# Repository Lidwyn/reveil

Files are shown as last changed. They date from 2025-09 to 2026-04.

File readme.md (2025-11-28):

# Alarm Clock Project

A fully custom-built **embedded alarm clock** designed from scratch, featuring a hardware-level implementation using an **ATmega328P**, **7-segment displays**, a **real-time clock (RTC)** module, and a modular audio system with microSD song storage.
This project integrates **embedded firmware**, **electronics design**, **PCB layout**, **CAD**, and **technical documentation**.

> This project is **still in progress**, every features or documents mentionned here might **not be complete or avaible yet**.

## Features
+ **Times display**
+ **Next alarm** on secondary display
+ Up to **15 one time (unique) and 15 weekly (non unique) independent alarms**
+ **Night Mode** - complete display blackout
+ **RTC-based accurate timekeeping** (with battery backup)

## Tech Stack & Tools

### Firmware
+ **Atmega328P** (bare-metal Arduino-style development)
+ **Arduino language** via **PlatformIO**
+ Interrupt-drivern logic
+ Low-power modes

### Elecrtonics & PCB
+ **Kicad** for schematic capture and PCB layout
+ Multi-voltage power stage (5V and 3.3V)

### Mechanical Design
+ **CATIA** for enclosure & mechanical parts

### Documentation
+ **LaTeX** for the user and technical manuals

## Project Architure
```
/Prog/          -> PlatformIO project for MCU firmware
/Schematic/     -> KiCad schematics & PCB files
/cad/           -> CATIA models for enclosure
/Latex/         -> Latex (and pdf) manual
```

## How It Works
1. The **ATmega328P** handles alarm logic, display control, and power management.
2. A **DS3231 RTC** maintains accurate time with battery backup. Through **I2C bus**.
3. On the same chips as the DS3231, we have an **AT24C32 EEPROM** that store the multiples alarms, the volume, and the brightness setup. Also with battery backup and through the same **I2C bus**.
4. Two four **7-segment display** and **9 leds**, driven by two **MAX7219** are in charge of the display. Through **SPI bus**.
5. A **DFPlayer** handle the audio, stored on a **microSD card**, with an integrated amplifier and an external speaker. Through a **Serial Port bus**.
5. 6 buttons for setup.

Find more information about the GUI on the manual:
- [Manuel fr](Latex/Manuel.pdf)

## Learning Objectives & Personal Development
This project in an opportunity to build **foundational embedded-systems skills** from scratch, inculding:
+ **Embedded C++ developpement** on microcontrollers
+ Designing and debugging **digital and mixed-signal electronics**
+ Understanting **RTCs**, **SD interfaces**, **multiplexing**, and **interrupt-driven systems**
+ **PCB worklow** from schematic to layout to fabrication
+ **Mechanical design** for electronics
+ Writing **clear and precise technical documentation** in **LaTeX**

## What I'm Most Proud Of
+ Implementing **deep sleep and interrupt-driven wake-up**, dramatically
reducing power consumption
+ Designing a **clean dual-voltage system** that support both 5V and 3.3V as the ATmega328P consumme less current at 3.3V further improving power consumption
+ Using **logical Mosfet** to cut unactive chips such as the audio chips, reducing noise to zero and reducing consumption
+ **Creating the entire device end-to-end** : firmware, electonics, PCB, mechanical parts, and documentation
+ Gaining practical **embedded engineering experience** from low to no prior knowledge

## How to Build / Run
### Hardware
1. Burn bootloader on the ATmega328P
2. Flash your microSD on FAT32
3. Insert microSD with you preferred alarm audio file with this typo `0001WhateverName.mp3`

### Firmware
1. Install **PlatformIO** (VS Codium extension)
2. Plug the alarm clock
3. Plug your computer into the USB C to seral adapter of the card
4. Adjust `upload_port = COM15` to your specific usb port in `/Prog/platformio.ini`
5. Upload firmware with `pio run --target upload`

## Status
This project is **still in development** :
+ Firmware : **working**, new features should be added and bugs fixed
+ PCB : **schematic is done**, PCB layout is not
+ Mechanical part : not started
+ Documenation : just the base of the french user manual version

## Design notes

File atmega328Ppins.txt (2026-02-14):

            +----_----+
  RESET   1 |PC6   PC5| 28 SCL
   RX->   2 |PD0   PC4| 27 SDA
   TX->   3 |PD1   PC3| 26 DS3231 CLK
Bouton<   4 |PD2   PC2| 25 
BoutonS   5 |PD3   PC1| 24 
BoutonA   6 |PD4   PC0| 23
    VCC   7 |         | 22 GND
    GND   8 |         | 21 AREF
DFP power 9 |PB6      | 20 AVCC
         10 |PB7   PB5| 19 MOSI
Bouton+  11 |PD5   PB4| 18 CS-1
Bouton>  12 |PD6   PB3| 17 CS-2
Bouton-  13 |PD7   PB2| 16 SCK
TX DFP-> 14 |PB0   PB1| 15 <-RX DFP
            +---------+

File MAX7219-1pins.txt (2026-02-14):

           +----_----+
     DIN  1 |DIN  DOUT| 24
     CCL  2 |D_0   S_D| 23 G/ddot
          3 |D_4  S_DP| 22 F
     GND  4 |GND   S_E| 21 A
     CC1  5 |D_6   S_C| 20 B
     CC2  6 |D_2   VCC| 19 VCC
     CC3  7 |D_3  ISET| 18 ISET
     CC4  8 |D_7   S_G| 17 
     GND  9 |GND   S_B| 16 C
         10 |D_5   S_F| 15 D
         11 |D_1   S_A| 14 E
    LOAD 12 |LOAD  CLK| 13 CLK
            +---------+

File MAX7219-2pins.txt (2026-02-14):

           +----_----+
     DIN  1 |DIN  DOUT| 24
     CC1  2 |D_0   S_D| 23 G/4
     CC2  3 |D_4  S_DP| 22 F/3
     GND  4 |GND   S_E| 21 A/2
     CC3  5 |D_6   S_C| 20 B/1
     CC4  6 |D_2   VCC| 19 VCC
     CCL  7 |D_3  ISET| 18 ISET
          8 |D_7   S_G| 17 C/5
     GND  9 |GND   S_B| 16 D/6
         10 |D_5   S_F| 15 E/7
         11 |D_1   S_A| 14
    LOAD 12 |LOAD  CLK| 13 CLK
            +---------+

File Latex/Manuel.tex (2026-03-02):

\documentclass{article}
\usepackage[T1]{fontenc} % Gestion des caractères (é et à)
\usepackage[utf8]{inputenc} % Encodage UTF-8
\usepackage{geometry} % Gestion des marges
\usepackage{fullpage} % Utiliser toute la page
\usepackage{enumitem} % listes personnalisées
\usepackage{amsmath} % Formules mathématiques
\usepackage{graphicx} % Insertion d'image
\usepackage[export]{adjustbox} % Ajuster la hauteur des images dans les minipages
\usepackage{caption} % Légendes
\usepackage{subcaption} % Sous légendes (pour plusieurs images en une)
\graphicspath{ {./fig/} } % Dossier d'images
\usepackage[many]{tcolorbox} % Boîtes colorées
\usepackage{indentfirst} % Identation du premier paragraphe
\usepackage{xparse} % Pour \NewDocumentCommand
\usepackage{fp}
\usepackage{tikz} % Graphique et annotations d'images
\usepackage{layout} % Affichage des marges
\usepackage{nameref} % Avoir le nom d'une section par un label
\usepackage{tocloft} % Pour gérer la map de la table des champ
\usepackage{bbding} % Avoir le caractère \Checkmark

\definecolor{boxlightgrey}{rgb}{0.8,0.8,0.8}
\definecolor{boxdarkgrey}{rgb}{0.25,0.25,0.25}

\geometry{ % zone de texte plus grande
    a4paper,
    hmargin = 3cm,
    top = 2cm
}

    % Packages mise en page : texte
\setlength\parindent{20pt}

    % Numero de section en lettre romaine
\renewcommand{\thesection}{\Roman{section}}
\renewcommand{\thesubsection}{\hspace{2pt} \Large \arabic{subsection}}
\renewcommand{\thesubsubsection}{\hspace{7pt} \large \arabic{subsection}.\arabic{subsubsection}}

    % Lettre encerclée
\newcommand*\circled[1]{\tikz[baseline=(char.base)]{
    \node[shape=circle,draw,inner sep=1pt] (char) {#1};}}
    % Annotation d'image

%\annotatedFigureBox{bottom left point}{top righ corner}{label}{label coordinate}[main color][backgroud color]
\NewDocumentCommand{\annotatedFigureBoxCustom}{m m m m O{black} O{white}}{
    \draw[#5,thick,rounded corners] (#1) rectangle (#2);
    \if\relax\detokenize{#3}\relax
        % empty
    \else
        \annotatedFigureLetter{#3}{#4}[#5][#6]
    \fi
}

%\annotatedFigureBox{xA}{yA}{width}{height}{label}{label pos}[main color][backgroud color]
\NewDocumentCommand{\annotatedFigureBox}{m m m m m m O{black} O{white}}{
    \FPeval{\xB}{#1 + #3}   % xB yB : top right corner
    \FPeval{\yB}{#2 + #4}
    \FPeval{\xC}{#1 + #3/2} % xC yC : midle point
    \FPeval{\yC}{#2 + #4/2}
    \ifnum#6=1 % getting label coordinate with the coordinate pos #6
        \def\a{#1}
        \def\b{#2}
    \else\ifnum#6=2
        \def\a{\xB}
        \def\b{#2}
    \else\ifnum#6=3
        \def\a{\xB}
        \def\b{\yB}
    \else\ifnum#6=4
        \def\a{#1}
        \def\b{\yB}
    \else\ifnum#6=5
        \def\a{\xC}
        \def\b{#2}
    \else\ifnum#6=6
        \def\a{\xB}
        \def\b{\yC}
    \else\ifnum#6=7
        \def\a{\xC}
        \def\b{\yB}
    \else\ifnum#6=8
        \def\a{#1}
        \def\b{\yC}
    \fi\fi\fi\fi\fi\fi\fi\fi
    \annotatedFigureBoxCustom{#1,#2}{\xB,\yB}{#5}{\a,\b}[#7][#8]
}

%\annotatedFigureLetterCustom{label}{x, y}[main color][backgroud color]
\NewDocumentCommand{\annotatedFigureLetter}{m m O{black} O{white}}{
    \node at (#2) [fill=#4,thick,shape=circle,draw=#3,inner sep=1pt,font=\sffamily,text=#3] {\small\textbf{#1}};
}

\newenvironment {annotatedFigure}[1]{\centering\begin{tikzpicture}[baseline=(top)]
    \node[anchor=south west,inner sep=0] (image) at (0,0) { #1};
    \begin{scope}[x={(image.south east)},y={(image.north west)}]}% BODY here
{\end{scope}
\path (current bounding box.north) ++(0pt,-\ht\strutbox) coordinate (top);
\end{tikzpicture}}

\title{MANUEL D'UTILISATION DU REVEIL}
\author{LIDWYN LE BARS}
\date{05 Juillet 2025}

\begin{document}
    % Ne pas afficher les \subsubsection{}
\addtocontents{toc}{\protect\setcounter{tocdepth}{2}}

\maketitle

\section{Introduction}

Ce réveil a pour fonctionnalité l'affichage de l'heure, et une alarme sonore qui se déclenche
automatiquement à une heure réglée en amont par l'utilisateur. De plus, le réveil a la capacité
d'enregistrer plusieurs alarmes qui ont une heure de déclenchement et les jours de la semaine où ils 
s'activent. On peut aussi supprimer l'affichage pour être dans le noir complet.

\section{Fonctionnalités et spécificités du réveil}

Le réveil permet l'affichage, le réglage de l'heure et de la luminosité. Il permet de configurer
plusieurs alarmes en simultané, et de les enregistrer même losqu'elles ne sont pas actives.
Par exemple, une alarme à 8h les lundis, mardis et mercredis, et une autre à 8h15 les jeudis et vendredis.
Les alarmes peuvents aussi être à usage unique et s'auto désarmer après une utilisation.

\section{Élement du réveil}

Voici la liste des éléments sur le réveil:

\begin{figure}[h!]
    \centering
    \begin{annotatedFigure}
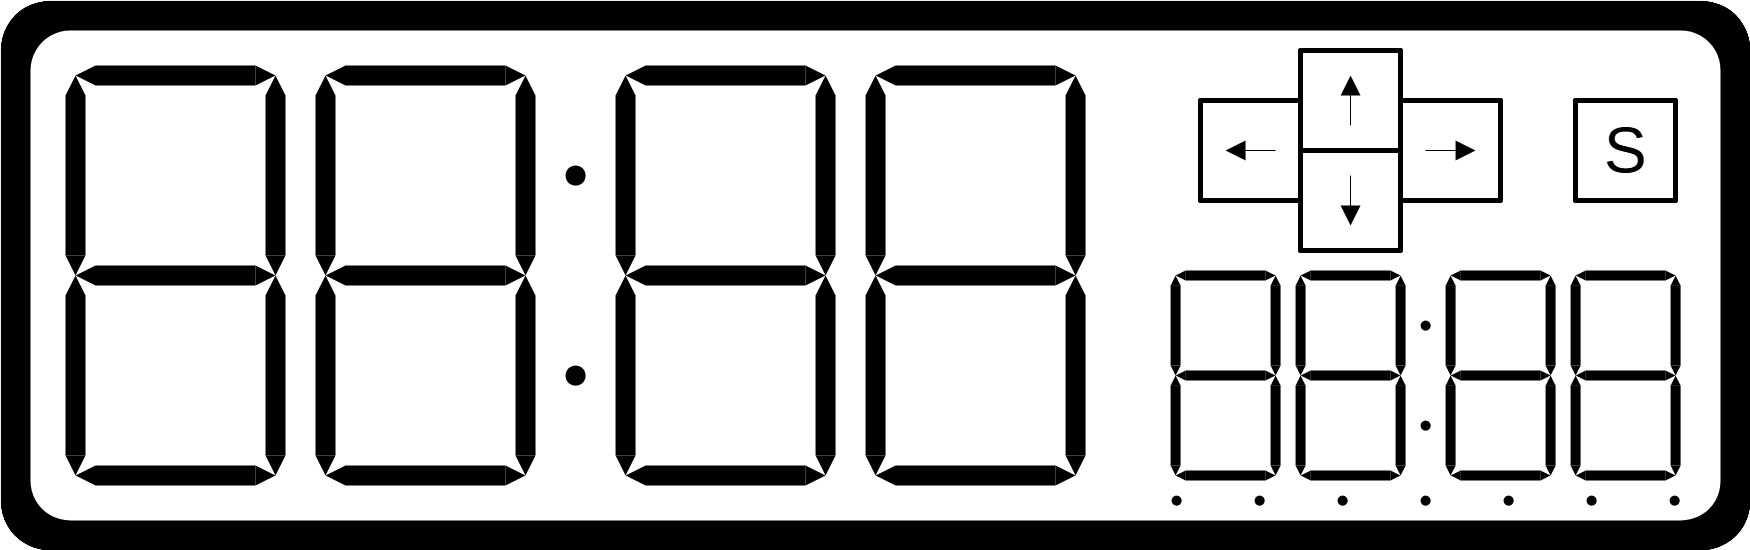
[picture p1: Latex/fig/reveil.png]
        {}
        \annotatedFigureBox{.026}{.08}{.608}{.833}{A}{5}[red]
        \annotatedFigureBox{.661}{.115}{.311}{.4}{B}{8}[red]
        \annotatedFigureBox{.678}{.53}{.19}{.4}{C}{4}[red]
        \annotatedFigureBox{.89}{.6}{.082}{.25}{D}{1}[red]
        \annotatedFigureBox{.651}{.065}{.321}{.05}{E}{8}[red]
        \annotatedFigureBox{.5}{1}{0}{0}{F}{1}[red]
    \end{annotatedFigure}
    \caption{Haching Tool}
    \label{fig:hachingTool1}
\end{figure}

\begin{itemize}
    \item \textbf{A} : Affichage 1 : heures et minutes
    \item \textbf{B} : Affichage 2 : heures et minutes de la prochaine alarme (éteint si aucune alarme
    active)
    \item \textbf{C} : 4 boutons directionnels, les boutons haut et bas sont aussi appelés plus et
    moins respectivement
    \item \textbf{D} : Bouton Setup
    \item \textbf{E} : 7 Leds pour l'affichage des jours de la semaine pour le réglage des alarmes
    \item \textbf{F} : un large bouton sur le dessus permettant l'arrêt de l'alarme ou le control de
    l'arrêt de l'affichage
\end{itemize}

\section{Réglage de l'heure}

Pour le réglage de l'heure, il faut tout d'abord appuyer sur le bouton setup (bouton S).
Lorsqu'on appui sur le bouton setup, on entre en mode modification de l'heure. Les secondes sont
affichées à droite et tout clignote à part l'heure. L'élément qui ne clignote pas (par défaut : l'heure)
est l'élément sélectionné qui peut être modifié avec les flèches "plus" et "moins". Pour passer d'un
élément à un autre, on utilise les flèches de gauche et de droite. Nous avons dans l'ordre:
\newline

Heures $\leftrightarrow$ Minutes $\leftrightarrow$ Secondes $\leftrightarrow$ Jours
$\leftrightarrow$ Mois $\leftrightarrow$ Année $\leftrightarrow$ Jour (quantième) de la semaine
\newline

Lors du passage de secondes à jours, l'interface change vers la deuxième "page" où l'on retrouve le jour
du mois sur les deux premiers digits de l'affichage principal,
le mois sur les deux derniers digits de l'affichage principal, l'année sur l'affichage secondaire et le
jour de la semaine (lundi, mardi etc.) est représenté sur les 7 leds en dessous du deuxième affichage,
ce paramètre doit aussi être réglé à la main.

\begin{enumerate}
    \item appuyer sur le bouton menu (Setup), l'affichage clignote sauf l'heure, et l'affichage secondaire
    affiche les secondes.
    \item reglage de l'heure (et des autres paramètres) avec les boutons haut et bas.
    \item selections du paramètre via les touches gauche et droite dans l'ordre :
    
    Heures $\leftrightarrow$ Minutes $\leftrightarrow$ Secondes $\leftrightarrow$ Jours $\leftrightarrow$
    Mois $\leftrightarrow$ Année $\leftrightarrow$ Jour de la semaine
    \item lorsque l'on clique sur le bouton droite alors que ce sont les secondes qui sont séléctionnées,
    on passe de la première page à la deuxième et inversement si l'on clique sur le bouton gauche lorsque
    les jours sont séléctionnés, on passe de la deuxième page à la première.
\end{enumerate}

\subsection{Appuyer sur le bouton menu}

Pour commencer on appuie sur le bouton menu/setup \circled{\textbf{A}}. 
On passe en mode réglage, et l'affichage de l'heure \circled{\textbf{B}} ne clignote pas tandis
que l'affichage des minutes \circled{\textbf{C}} et des secondes \circled{\textbf{D}} eux clignotent.

\begin{figure}[h!]
    \centering
    \begin{annotatedFigure}
        {}
        \annotatedFigureBox{.026}{.08}{.288}{.833}{B}{2}[red]
        \annotatedFigureBox{.342}{.08}{.288}{.833}{C}{2}[red]
        \annotatedFigureBox{.661}{.115}{.311}{.4}{D}{8}[red]
        \annotatedFigureBox{.89}{.6}{.082}{.25}{A}{1}[red]
    \end{annotatedFigure}
    \caption{passage en mode modification}
    \label{bouton menu}
\end{figure}

\clearpage  %______________________________/!\_clearpage_/!\_____________________________

\subsection{Réglage des paramètres}

Dans ce mode on peut régler les paramètres lorsqu'ils sont sélectionnés.
Pour ce faire, il faut utiliser les bouton plus et moins \circled{\textbf{D}}.

\begin{figure}[h!]
    \centering
    \begin{annotatedFigure}
        {}
        \annotatedFigureBox{.738}{.53}{.07}{.4}{D}{4}[red]
    \end{annotatedFigure}
    \caption{bouton haut et bas}
    \label{bouton haut et bas}
\end{figure}

\vspace{-15pt}
\subsection{Séléction des paramètres}

Il y a 7 paramètres réglables dans l'ordre :
\begin{itemize}
    \item fig4 : Heure \circled{\textbf{G}}, Minute \circled{\textbf{H}}, Seconde \circled{\textbf{I}}
    \item fig5 : Jour \circled{\textbf{J}}, Mois \circled{\textbf{K}}, Année \circled{\textbf{L}}, Jour de la semaine \circled{\textbf{M}}
\end{itemize}

Pour passer d'un paramètre à l'autre, il faut utiliser les boutons droite \circled{\textbf{E}} et gauche \circled{\textbf{F}}.

\begin{figure}[h!]
    \centering
    \begin{annotatedFigure}
        {}
        \annotatedFigureBox{.675}{.6}{.082}{.25}{E}{1}[red]
        \annotatedFigureBox{.79}{.6}{.082}{.25}{F}{2}[red]
        \annotatedFigureBox{.026}{.08}{.288}{.833}{G}{3}[red]
        \annotatedFigureBox{.344}{.08}{.288}{.833}{H}{1}[red]
        \annotatedFigureBox{.661}{.115}{.15}{.4}{I}{8}[red]
    \end{annotatedFigure}
    \caption{bouton droite et gauche, heure, minute et seconde}
    \label{page 1 reglage}
\end{figure}

Lorsque les secondes sont sélectionnées et qu'on appuie sur le bouton droite, on passe sur la deuxième page.
Pour revenir à la première page, il faut appuyer sur le bouton gauche lorsque les jours sont séléctionnés.

\begin{figure}[h!]
    \centering
    \begin{annotatedFigure}
        {}
        \annotatedFigureBox{.026}{.08}{.288}{.833}{J}{3}[red]
        \annotatedFigureBox{.344}{.08}{.288}{.833}{K}{1}[red]
        \annotatedFigureBox{.661}{.115}{.311}{.4}{L}{8}[red]
        \annotatedFigureBox{.651}{.065}{.321}{.05}{M}{8}[red]
        \annotatedFigureBox{.89}{.6}{.082}{.25}{N}{1}[red]
    \end{annotatedFigure}
    \caption{Page 2}
    \label{page 2 reglage}
\end{figure}

Ceci fait, on peut sortir du mode de réglage de l'heure en appuyant sur le bouton setup \circled{\textbf{N}}.

\clearpage  %______________________________/!\_clearpage_/!\_____________________________

\section{Alarmes}

\subsection{Les deux types d'alarmes}

On peut enregister jusqu'à 30 alarmes. Il y a deux catégories d'alarmes:
\begin{enumerate}
    \item Les alarmes permanantes : sonnent selon une période hebdommadaire.
    \item Les alarmes éphémères : ne sonnent qu'une seule fois puis se désarment.
\end{enumerate}

Il y a donc jusqu'à 15 de chaque et les deux types ont leur page respective dans menu des alarmes.

\subsection{Lorsque l'alarme sonne}

Lorsqu'une alarme sonne, on a un signal sonore modifiable sur la carte microSD avec un fichier mp3.
L'affichage se met à cligonter. Pour couper l'alarme, il suffit d'appuyer sur le bouton large sur le dessus du  réveil.

S'il s'agit d'une alarme éphémère, elle se désactive automatiquement.

\subsection{Menu des alarmes}

Les alarmes ont un menu associés qui permet :

\begin{itemize}
    \item L'activation ou la désactivation des alarmes
    \item La création de nouvelles alarmes
    \item La modification ou la suppression d'alarmes existantes
\end{itemize}

Ce menu est accèssible en appuyant sur le bouton droite \circled{\textbf{A}}.

\begin{figure}[h!]
    \centering
    \begin{annotatedFigure}
        {}
        \annotatedFigureBox{.79}{.6}{.082}{.25}{A}{2}[red]
    \end{annotatedFigure}
    \caption{Entrer dans le menu des réveils}
    \label{affichage 2 reglage}
\end{figure}

Lorsque l'on entre de le menu des alarmes, on arrive sur le sous menu lié au alarmes hebdommadaire,
sur la prermière alarme, qui peut être inexistante et dans ce cas on nous proposer de la créer
(voir section "Création d'une nouvelle alarme").
\clearpage  %______________________________/!\_clearpage_/!\_____________________________
Sur l'affichage du menu des alarmes on retrouve ces informations :

\begin{figure}[h!]
    \centering
    \begin{annotatedFigure}
        {}
        \annotatedFigureBox{.026}{.08}{.608}{.833}{A}{5}[red]
        \annotatedFigureBox{.661}{.115}{.308}{.408}{B}{4}[red]
        \annotatedFigureBox{.651}{.065}{.321}{.05}{C}{8}[red]
        \annotatedFigureBox{.313}{.15}{.034}{.703}{D}{6}[red]
    \end{annotatedFigure}
    \caption{Affichage du menu des alarmes}
    \label{affichage 2 reglage}
\end{figure}

\begin{itemize}
    \item L'heure à laquelle sonne l'alarme \circled{\textbf{A}}
    \item Le numéro de l'alarme \circled{\textbf{B}} (de 1 à 15)
    \item les jours de la semaine auxquels l'alarme sonne \circled{\textbf{C}} (lundi à gauche jusque
    dimanche à droite). Si toute les leds sont désactivées, alors il s'agit du menu pour les alarmes éphémères
    \item État armé ou non de l'alarme, allumé = armé
\end{itemize}

\subsection{Création d'une nouvelle alarme}

Lorsque le l'affichage n'affiche qu'un tiret sur l'écran de gauche, cela veut dire qu'il n'y pas plus
d'alarmes existantes et donc que l'on peut en créer une nouvelle. pour ce faire on clique sur le bouton
setup pour entrer dans le mode modification/création d'une nouvelle alarme. l'heure de base est réglée sur 12h00.

Ce menu de modification de l'alarme est très similaire à celui pour régler l'heure actuelle, pour les paramètres
de l'heure de l'alarme et des minutes. Ensuite on peut modifier les jours de la semaine, pour ce faire,
lorsque l'on clique sur le bouton de droite alors que l'on est sur les minutes, on a un chiffres qui
s'affiche sur le deuxième écran correspondant au jour de la semaine (1 = lundi jusqu'à 7 = dimanche).
Pour activer un jour on clique sur le bouton plus et pour le désactiver sur le bouton moins.

\subsection{Modification d'une alarme existante}

Pour modifier une alarme existante, lorsqu'elle est affichée dans le menu réveil, on appui sur le bouton setup.
Une fois que c'est fait on a le même menu de modification que pour la création.

\section{Réglage de l'affichage}

On peut régler l'intensité de l'affichage avec les boutons plus et moins.
Et on peut supprimer l'affichage avec le bouton sur le dessus du réveil.

\end{document}

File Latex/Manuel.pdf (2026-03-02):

## MANUEL D'UTILISATION DU REVEIL

LIDWYN LE BARS

05 Juillet 2025

I Introduction Ce réveil a pour fonctionnalité l'achage de l'heure, et une alarme sonore qui se déclenche

automatiquement à une heure réglée en amont par l'utilisateur. De plus, le réveil a la capacité d'enregistrer plusieurs alarmes qui ont une heure de déclenchement et les jours de la semaine où ils s'activent. On peut aussi supprimer l'achage pour être dans le noir complet.

II Fonctionnalités et spécicités du réveil Le réveil permet l'achage, le réglage de l'heure et de la luminosité. Il permet de congurer

plusieurs alarmes en simultané, et de les enregistrer même losqu'elles ne sont pas actives. Par exemple, une alarme à 8h les lundis, mardis et mercredis, et une autre à 8h15 les jeudis et vendredis. Les alarmes peuvents aussi être à usage unique et s'auto désarmer après une utilisation.

## III Élement du réveil Voici la liste des éléments sur le réveil:

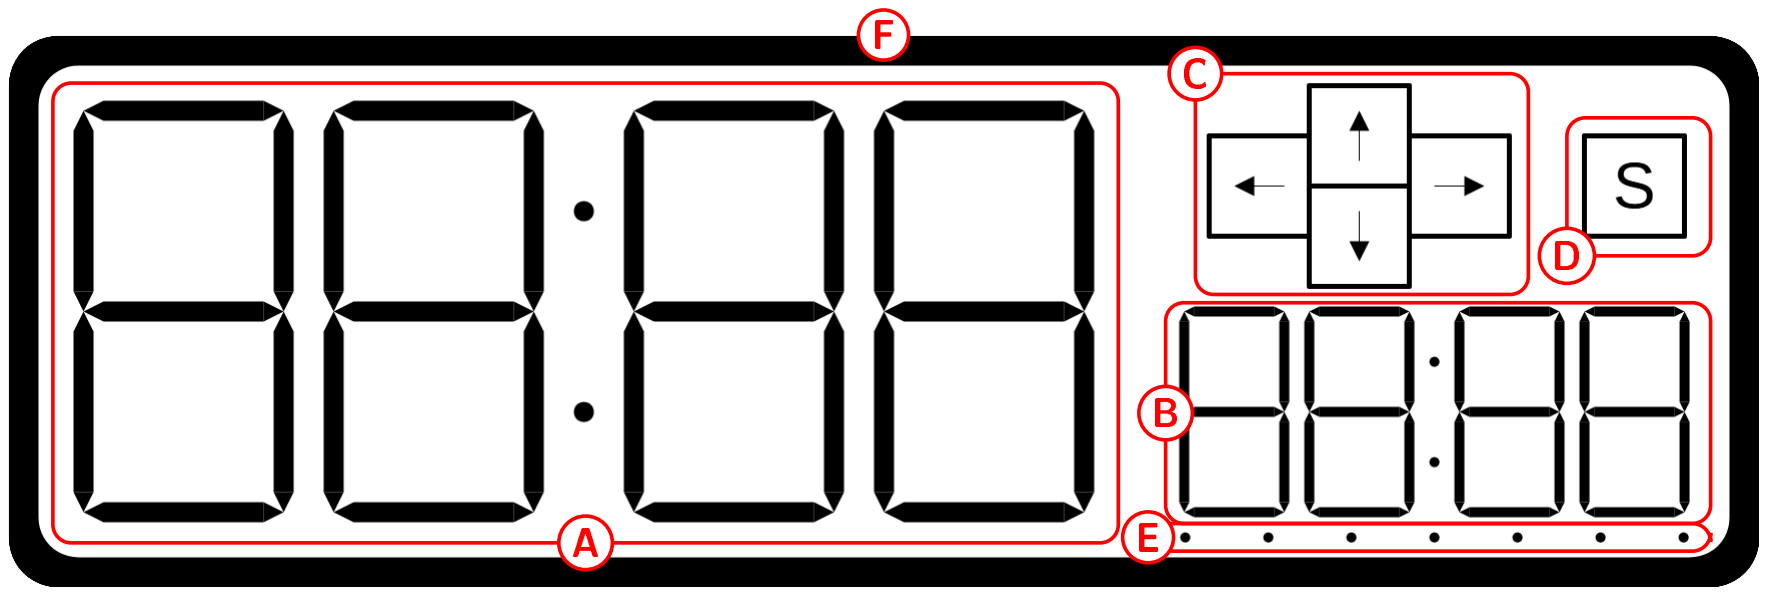
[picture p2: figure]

Figure 1: Haching Tool

| A : Achage 1 : heures et minutes
| B : Achage 2 : heures et minutes de la prochaine alarme (éteint si aucune alarme active)
| C : 4 boutons directionnels, les boutons haut et bas sont aussi appelés plus et moins respec- tivement
| D : Bouton Setup
| E : 7 Leds pour l'achage des jours de la semaine pour le réglage des alarmes
| F : un large bouton sur le dessus permettant l'arrêt de l'alarme ou le control de l'arrêt de l'achage

1

IV Réglage de l'heure Pour le réglage de l'heure, il faut tout d'abord appuyer sur le bouton setup (bouton S).

Lorsqu'on appui sur le bouton setup, on entre en mode modication de l'heure. Les secondes sont achées à droite et tout clignote à part l'heure. L'élément qui ne clignote pas (par défaut : l'heure) est l'élément sélectionné qui peut être modié avec les èches "plus" et "moins". Pour passer d'un élément à un autre, on utilise les èches de gauche et de droite. Nous avons dans l'ordre:

| Heures ↔ Minutes ↔ Secondes ↔ Jours ↔ Mois ↔ Année ↔ Jour (quantième) de la semaine Lors du passage de secondes à jours, l'interface change vers la deuxième "page" où l'on retrouve

le jour du mois sur les deux premiers digits de l'achage principal, le mois sur les deux derniers digits de l'achage principal, l'année sur l'achage secondaire et le jour de la semaine (lundi, mardi etc.) est représenté sur les 7 leds en dessous du deuxième achage, ce paramètre doit aussi être réglé à la main.

1. appuyer sur le bouton menu (Setup), l'achage clignote sauf l'heure, et l'achage secondaire
| ache les secondes.
2. reglage de l'heure (et des autres paramètres) avec les boutons haut et bas.
3. selections du paramètre via les touches gauche et droite dans l'ordre :
| Heures ↔ Minutes ↔ Secondes ↔ Jours ↔ Mois ↔ Année ↔ Jour de la semaine
4. lorsque l'on clique sur le bouton droite alors que ce sont les secondes qui sont séléctionnées,
| on passe de la première page à la deuxième et inversement si l'on clique sur le bouton gauche lorsque les jours sont séléctionnés, on passe de la deuxième page à la première.
1 | Appuyer sur le bouton menu Pour commencer on appuie sur le bouton menu/setup A . On passe en mode réglage, et

l'achage de l'heure B ne clignote pas tandis que l'achage des minutes C et des secondes D

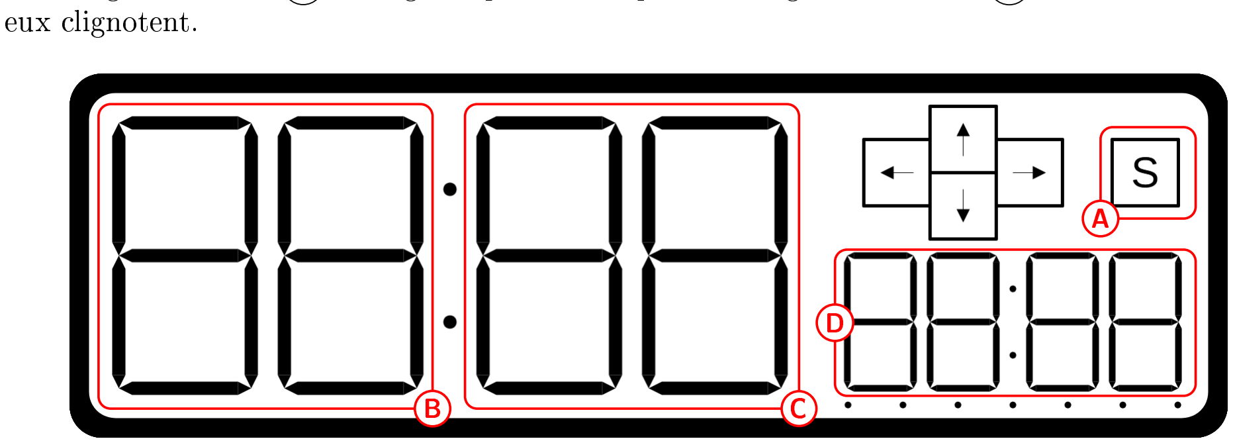
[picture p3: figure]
eux clignotent.

Figure 2: passage en mode modication

2

2 | Réglage des paramètres
| Dans ce mode on peut régler les paramètres lorsqu'ils sont sélectionnés. Pour ce faire, il faut
utiliser les bouton plus et moins D .

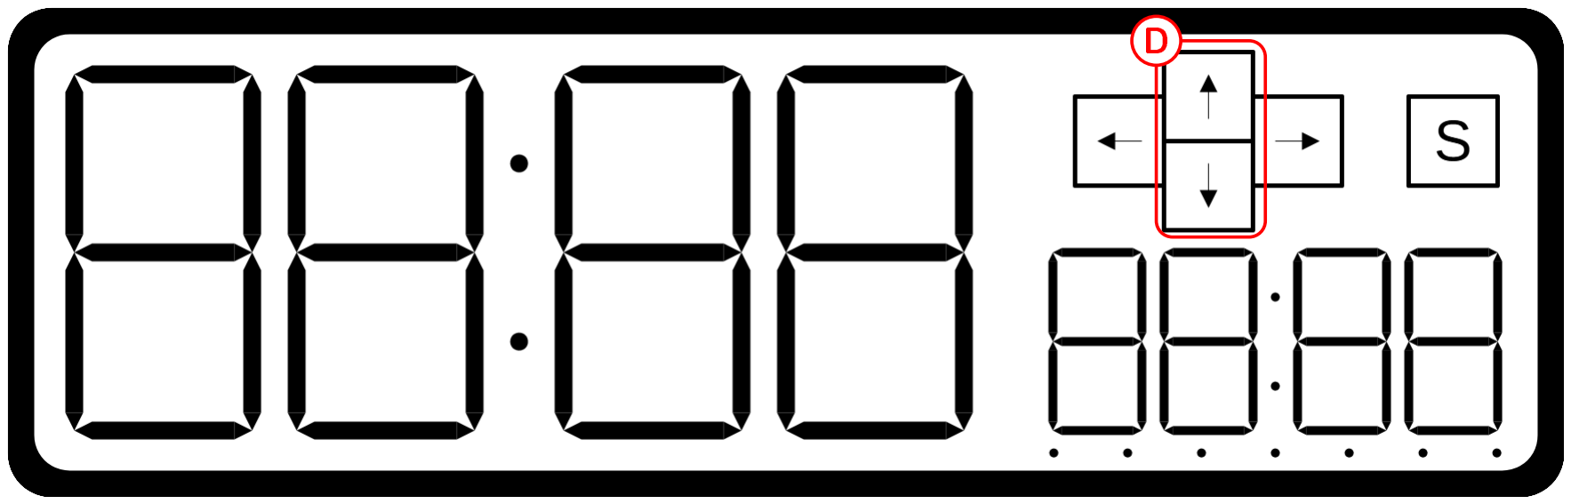
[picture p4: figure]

Figure 3: bouton haut et bas

3 | Séléction des paramètres
| Il y a 7 paramètres réglables dans l'ordre :

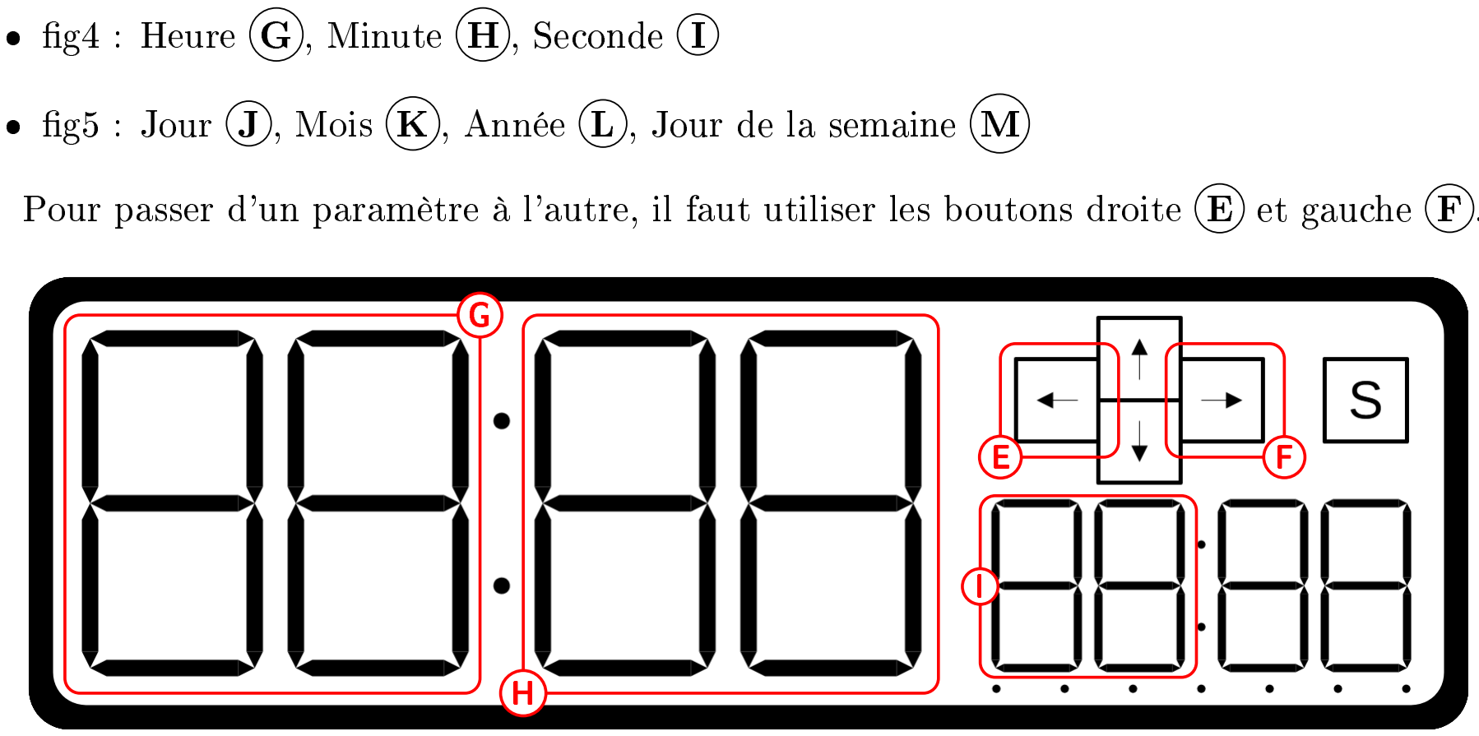
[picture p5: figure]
g4 : Heure G , Minute H , Seconde I

| g5 : Jour J , Mois K , Année L , Jour de la semaine M

Pour passer d'un paramètre à l'autre, il faut utiliser les boutons droite E et gauche F .

Figure 4: bouton droite et gauche, heure, minute et seconde

Lorsque les secondes sont sélectionnées et qu'on appuie sur le bouton droite, on passe sur la deuxième page. Pour revenir à la première page, il faut appuyer sur le bouton gauche lorsque les

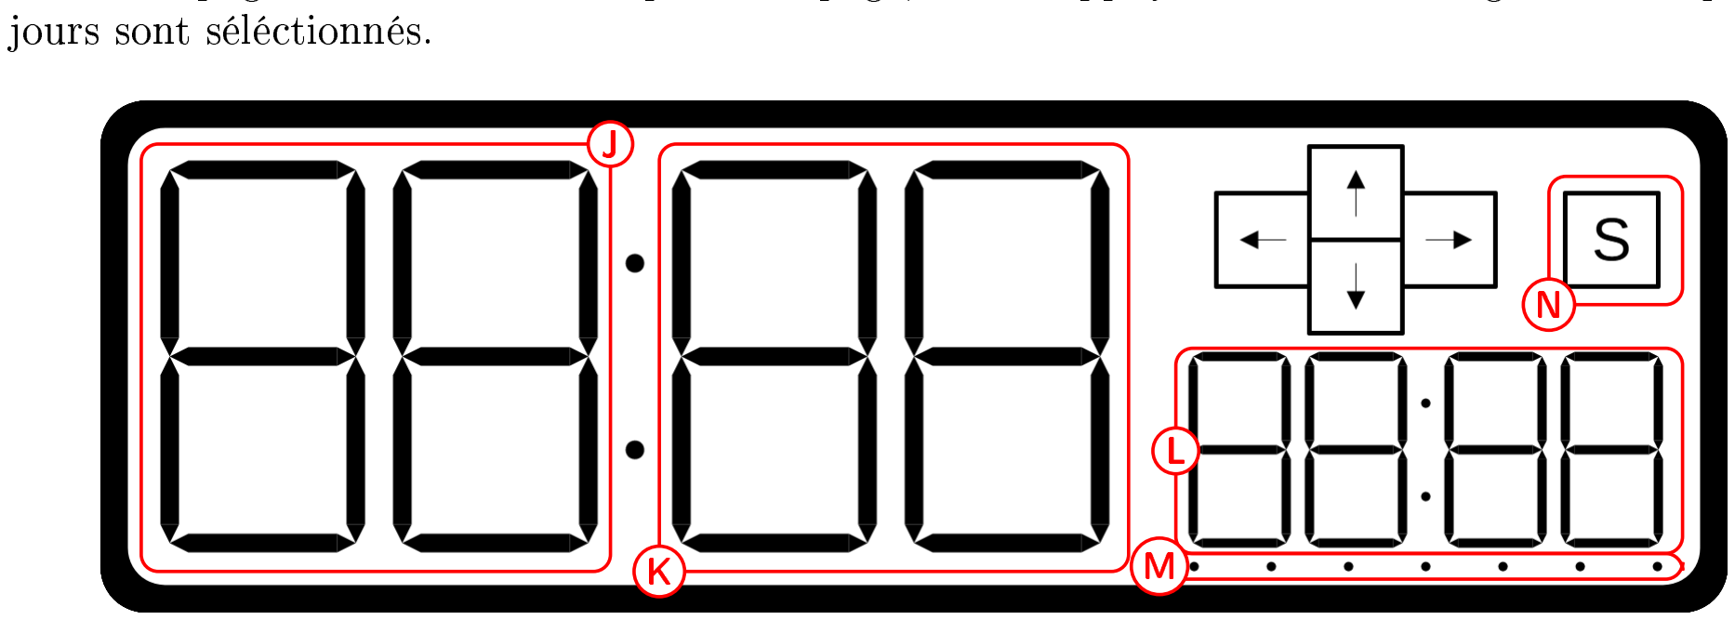
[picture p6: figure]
jours sont séléctionnés.

Figure 5: Page 2

Ceci fait, on peut sortir du mode de réglage de l'heure en appuyant sur le bouton setup N .

3

V | Alarmes
1 | Les deux types d'alarmes

On peut enregister jusqu'à 30 alarmes. Il y a deux catégories d'alarmes:

1. Les alarmes permanantes : sonnent selon une période hebdommadaire.
2. Les alarmes éphémères : ne sonnent qu'une seule fois puis se désarment.

Il y a donc jusqu'à 15 de chaque et les deux types ont leur page respective dans menu des alarmes.

2 Lorsque l'alarme sonne

Lorsqu'une alarme sonne, on a un signal sonore modiable sur la carte microSD avec un chier mp3. L'achage se met à cligonter. Pour couper l'alarme, il sut d'appuyer sur le bouton large sur le dessus du réveil.
S'il s'agit d'une alarme éphémère, elle se désactive automatiquement.

3 Menu des alarmes

Les alarmes ont un menu associés qui permet :

| L'activation ou la désactivation des alarmes
| La création de nouvelles alarmes
| La modication ou la suppression d'alarmes existantes

Ce menu est accèssible en appuyant sur le bouton droite A .

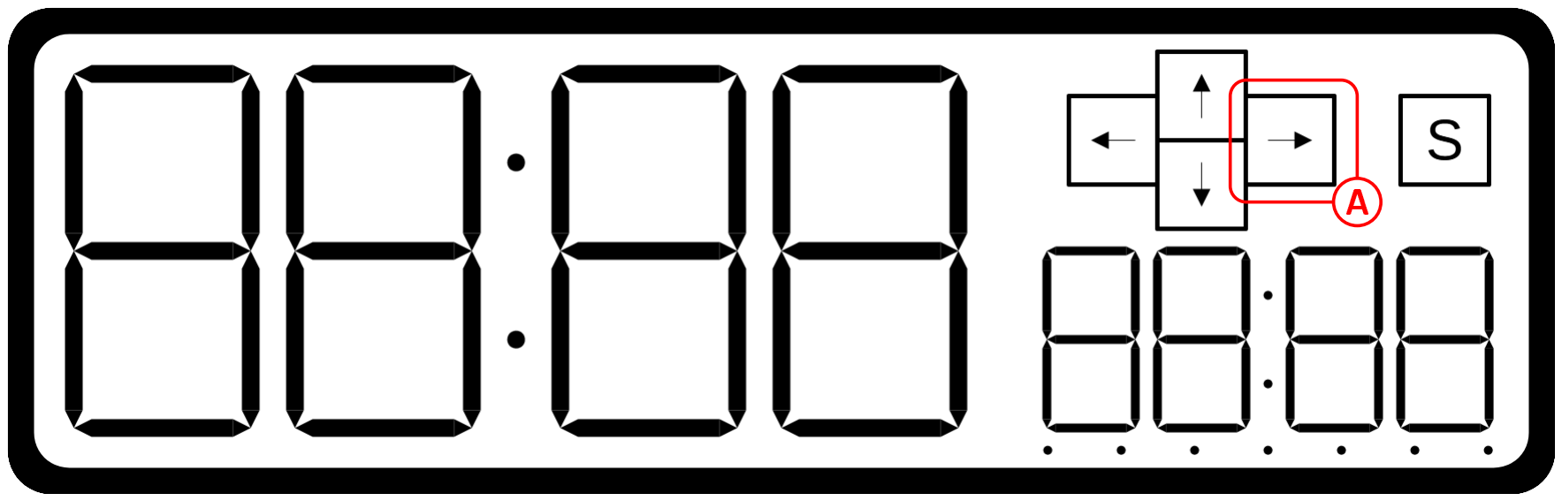
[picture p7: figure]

Figure 6: Entrer dans le menu des réveils

Lorsque l'on entre de le menu des alarmes, on arrive sur le sous menu lié au alarmes hebdommadaire, sur la prermière alarme, qui peut être inexistante et dans ce cas on nous proposer de la créer (voir section "Création d'une nouvelle alarme").

4

Sur l'achage du menu des alarmes on retrouve ces informations :

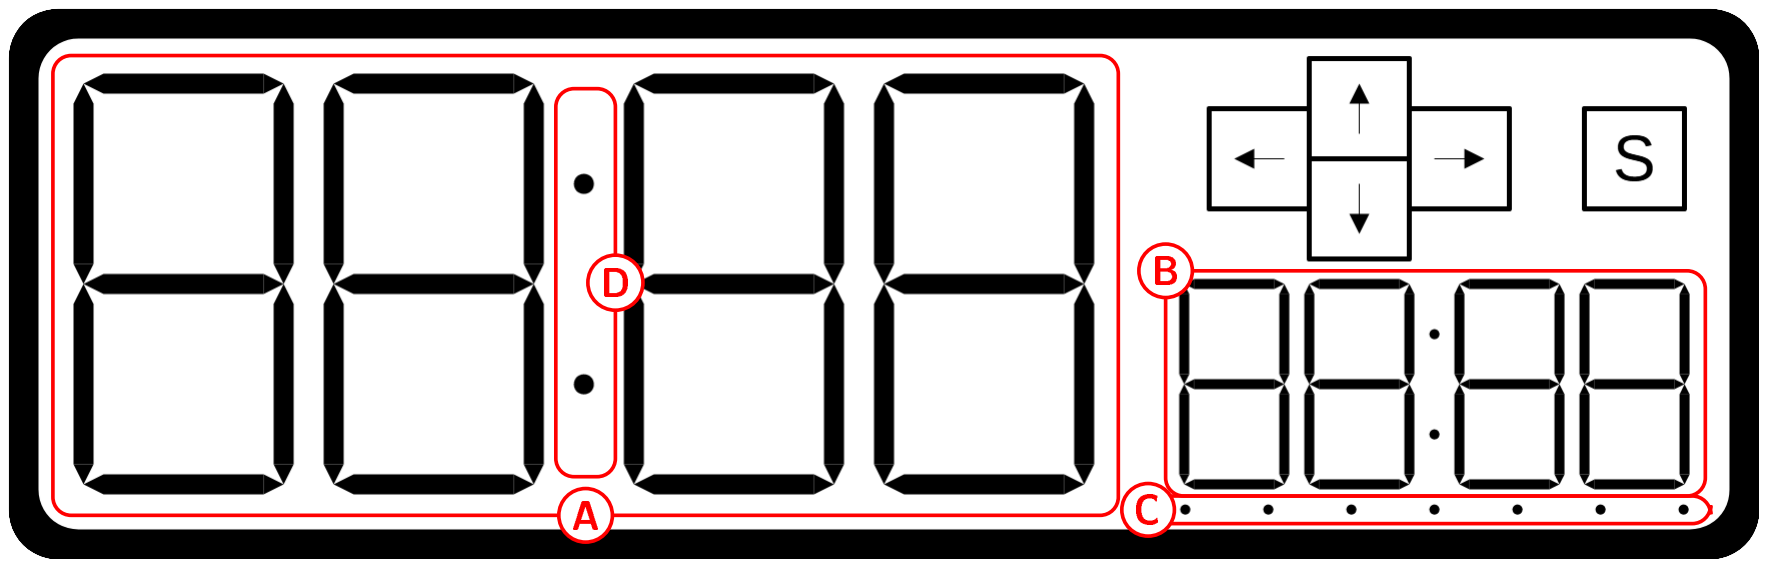
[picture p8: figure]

Figure 7: Achage du menu des alarmes

| L'heure à laquelle sonne l'alarme A
| Le numéro de l'alarme B (de 1 à 15)
| les jours de la semaine auxquels l'alarme sonne C (lundi à gauche jusque dimanche à droite). Si toute les leds sont désactivées, alors il s'agit du menu pour les alarmes éphémères
| État armé ou non de l'alarme, allumé = armé
4 | Création d'une nouvelle alarme

Lorsque le l'achage n'ache qu'un tiret sur l'écran de gauche, cela veut dire qu'il n'y pas plus d'alarmes existantes et donc que l'on peut en créer une nouvelle. pour ce faire on clique sur le bouton setup pour entrer dans le mode modication/création d'une nouvelle alarme. l'heure de base est réglée sur 12h00.
Ce menu de modication de l'alarme est très similaire à celui pour régler l'heure actuelle, pour les paramètres de l'heure de l'alarme et des minutes. Ensuite on peut modier les jours de la semaine, pour ce faire, lorsque l'on clique sur le bouton de droite alors que l'on est sur les minutes, on a un chires qui s'ache sur le deuxième écran correspondant au jour de la semaine (1 = lundi jusqu'à 7 = dimanche). Pour activer un jour on clique sur le bouton plus et pour le désactiver sur le bouton moins.

5 Modication d'une alarme existante

Pour modier une alarme existante, lorsqu'elle est achée dans le menu réveil, on appui sur le bouton setup. Une fois que c'est fait on a le même menu de modication que pour la création.

## VI Réglage de l'achage

On peut régler l'intensité de l'achage avec les boutons plus et moins. Et on peut supprimer l'achage avec le bouton sur le dessus du réveil.

5

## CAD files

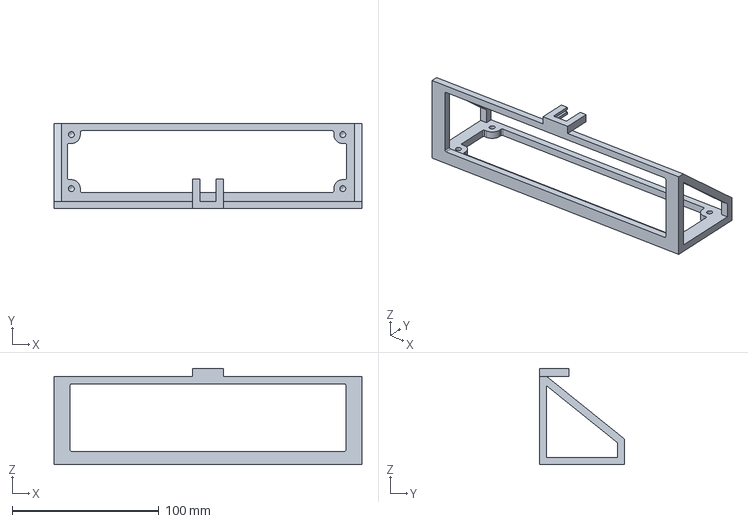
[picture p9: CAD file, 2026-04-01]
3D/simpleFrame/frame.FCStd
209.7 x 58.0 x 65.5 mm

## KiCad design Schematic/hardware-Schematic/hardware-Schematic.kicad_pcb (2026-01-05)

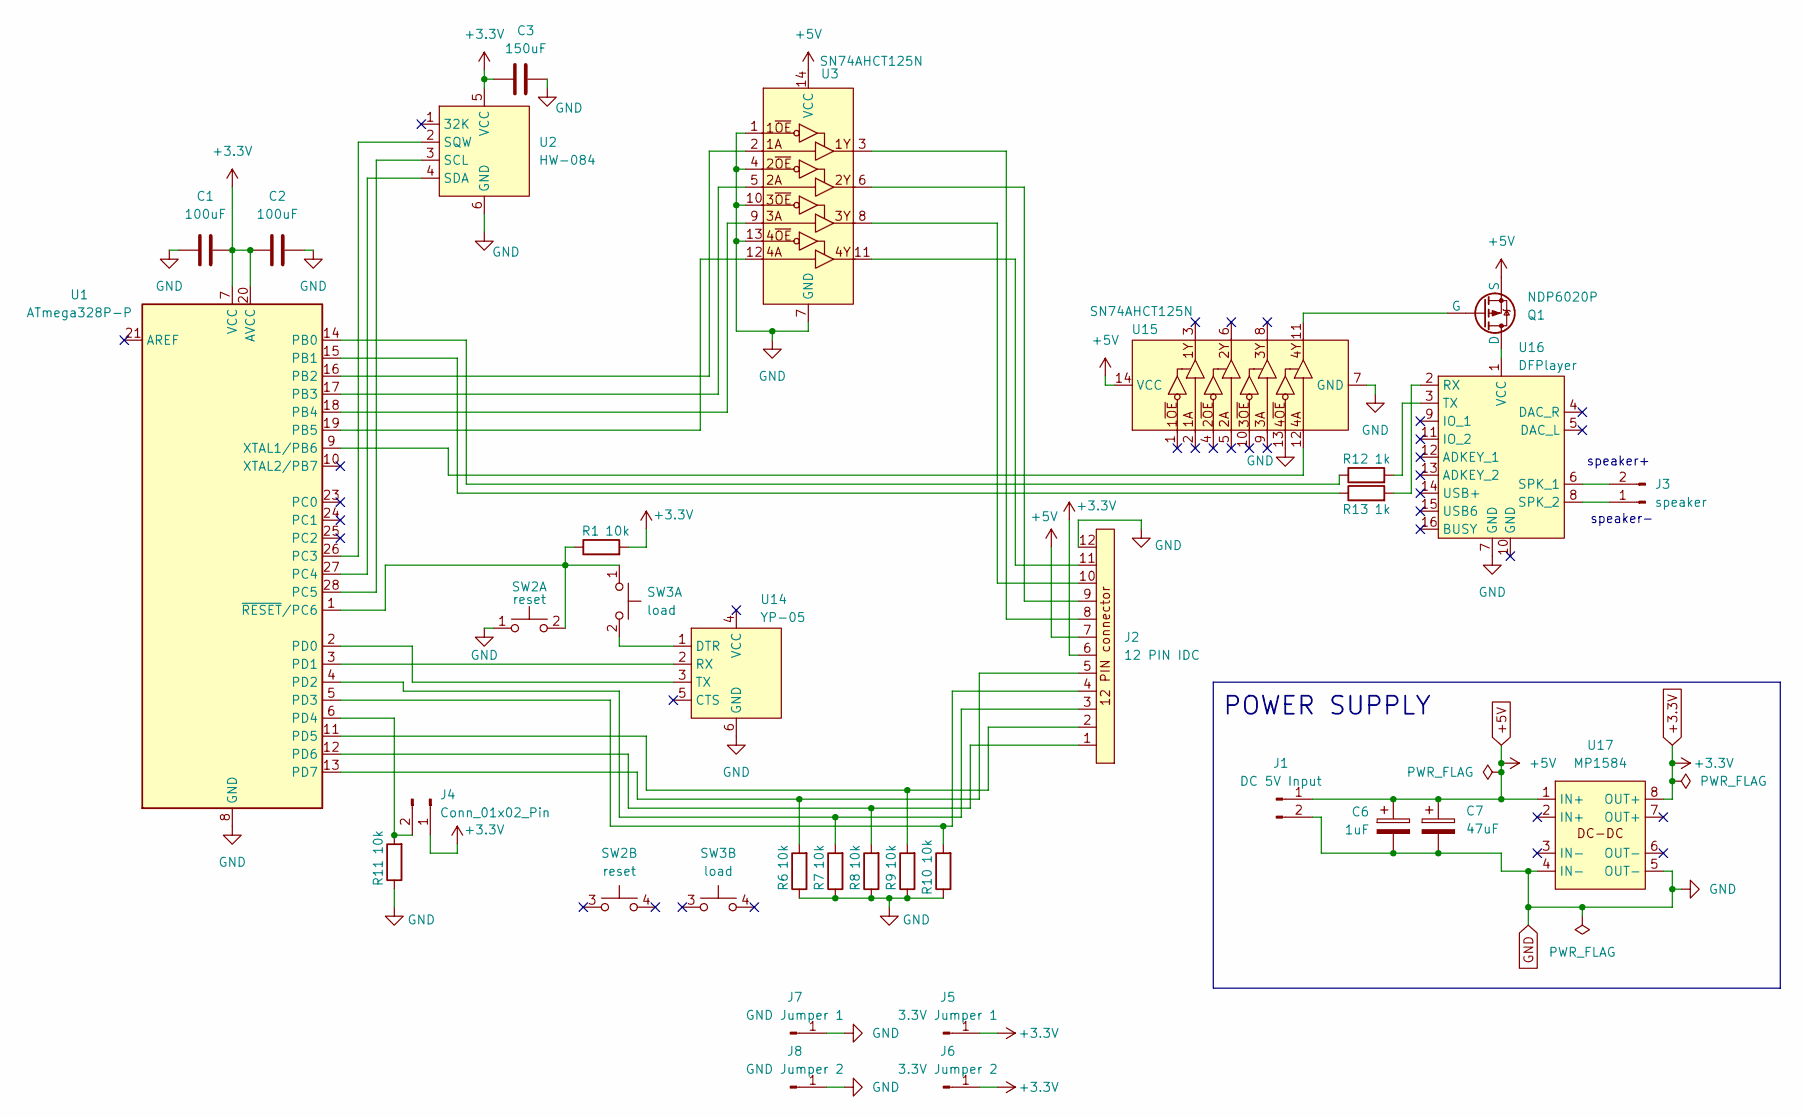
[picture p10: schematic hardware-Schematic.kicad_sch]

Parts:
C1, C2: 100uF; C_Axial_L12.0mm_D6.5mm_P15.00mm_Horizontal
C3: 150uF; C_Rect_L7.2mm_W3.0mm_P5.00mm_FKS2_FKP2_MKS2_MKP2
C6: 1uF; CP_Radial_D5.0mm_P2.50mm
C7: 47uF; CP_Radial_D5.0mm_P2.50mm
J1: DC 5V Input; USB-C DC input 5V
J2: 12 PIN IDC; IDC-Header_2x06_P2.54mm_Vertical
J3: speaker; TopButton
J4: Conn_01x02_Pin; R_Axial_DIN0207_L6.3mm_D2.5mm_P10.16mm_Horizontal
J5: 3.3V Jumper 1; Pin_D0.7mm_L6.5mm_W1.8mm_FlatFork
J6: 3.3V Jumper 2; Pin_D0.7mm_L6.5mm_W1.8mm_FlatFork
J7: GND Jumper 1; Pin_D0.7mm_L6.5mm_W1.8mm_FlatFork
J8: GND Jumper 2; Pin_D0.7mm_L6.5mm_W1.8mm_FlatFork
Q1: NDP6020P; TO-220F-3_Vertical
R1, R6, R7, R8, R9, R10, R11: 10k; R_Axial_DIN0207_L6.3mm_D2.5mm_P10.16mm_Horizontal
R12, R13: 1k; R_Axial_DIN0207_L6.3mm_D2.5mm_P10.16mm_Horizontal
SW2: reset; SW_PUSH_6mm
SW3: load; SW_PUSH_6mm
U1: ATmega328P-P; DIP-28_W7.62mm
U2: HW-084; HW-084_YP-05
U3, U15: SN74AHCT125N; DIP-14_W7.62mm
U14: YP-05; HW-084_YP-05
U16: DFPlayer
U17: MP1584

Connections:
+3.3V: C1.2, C2.1, C3.1, J2.6, J4.1, J5.1, J6.1, R1.2, U1.7 (VCC), U1.20 (AVCC), U2.5 (VCC), U17.8 (OUT+)
+5V: C6.1, C7.1, J1.1, J2.7, Q1.3 (S), U3.14 (VCC), U15.14 (VCC), U17.1 (IN+)
GND: C1.1, C2.2, C3.2, C6.2, C7.2, J1.2, J2.12, J7.1, J8.1, R6.1, R7.1, R8.1, R9.1, R10.1, R11.1, SW2.1 (C), U1.8 (GND), U1.22 (GND), U2.6 (GND), U3.1, U3.4, U3.7 (GND), U3.10, U3.13, U14.6 (GND), U15.7 (GND), U15.13, U16.7 (GND), U17.4 (IN-), U17.5 (OUT-)
unnamed: J2.8, U3.3
unnamed: J2.9, U3.6
unnamed: J2.10, U3.8
unnamed: J2.11, U3.11
unnamed: J3.1, U16.8 (SPK_2)
unnamed: J3.2, U16.6 (SPK_1)
unnamed: J4.2, R11.2, U1.6 (PD4)
unnamed: Q1.1 (D), U16.1 (VCC)
unnamed: Q1.2 (G), U15.11
unnamed: R1.1, SW2.2 (D), SW3.1 (C), U1.1 (~RESET/PC6)
unnamed: SW3.2 (D), U14.1 (DTR)
unnamed: R12.1, U1.14 (PB0)
unnamed: R13.1, U1.15 (PB1)
unnamed: U1.16 (PB2), U3.2
unnamed: U1.17 (PB3), U3.5
unnamed: U1.18 (PB4), U3.9
unnamed: U1.19 (PB5), U3.12
unnamed: U1.26 (PC3), U2.2 (SQW)
unnamed: U1.27 (PC4), U2.4 (SDA)
unnamed: U1.28 (PC5), U2.3 (SCL)
unnamed: U1.2 (PD0), U14.3 (TX)
unnamed: U1.3 (PD1), U14.2 (RX)
unnamed: J2.3, R7.2, U1.4 (PD2)
unnamed: J2.4, R10.2, U1.5 (PD3)
unnamed: J2.2, R9.2, U1.11 (PD5)
unnamed: J2.1, R8.2, U1.12 (PD6)
unnamed: J2.5, R6.2, U1.13 (PD7)
unnamed: U1.9 (XTAL1/PB6), U15.12
unnamed: R13.2, U16.2 (RX)
unnamed: R12.2, U16.3 (TX)

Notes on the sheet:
POWER SUPPLY
speaker+
speaker-

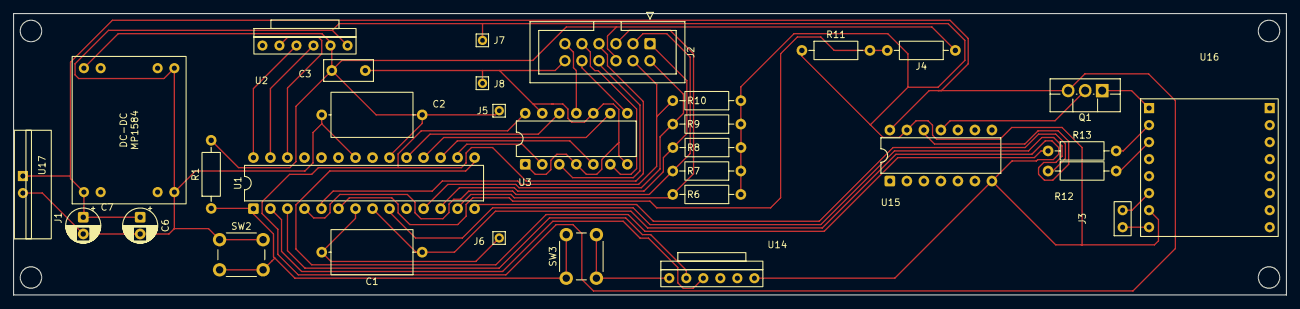
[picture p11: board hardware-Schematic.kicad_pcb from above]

Board: 2 copper layers, 190.0 x 42.0 mm, 32 parts (0 on the bottom side), 33 nets.

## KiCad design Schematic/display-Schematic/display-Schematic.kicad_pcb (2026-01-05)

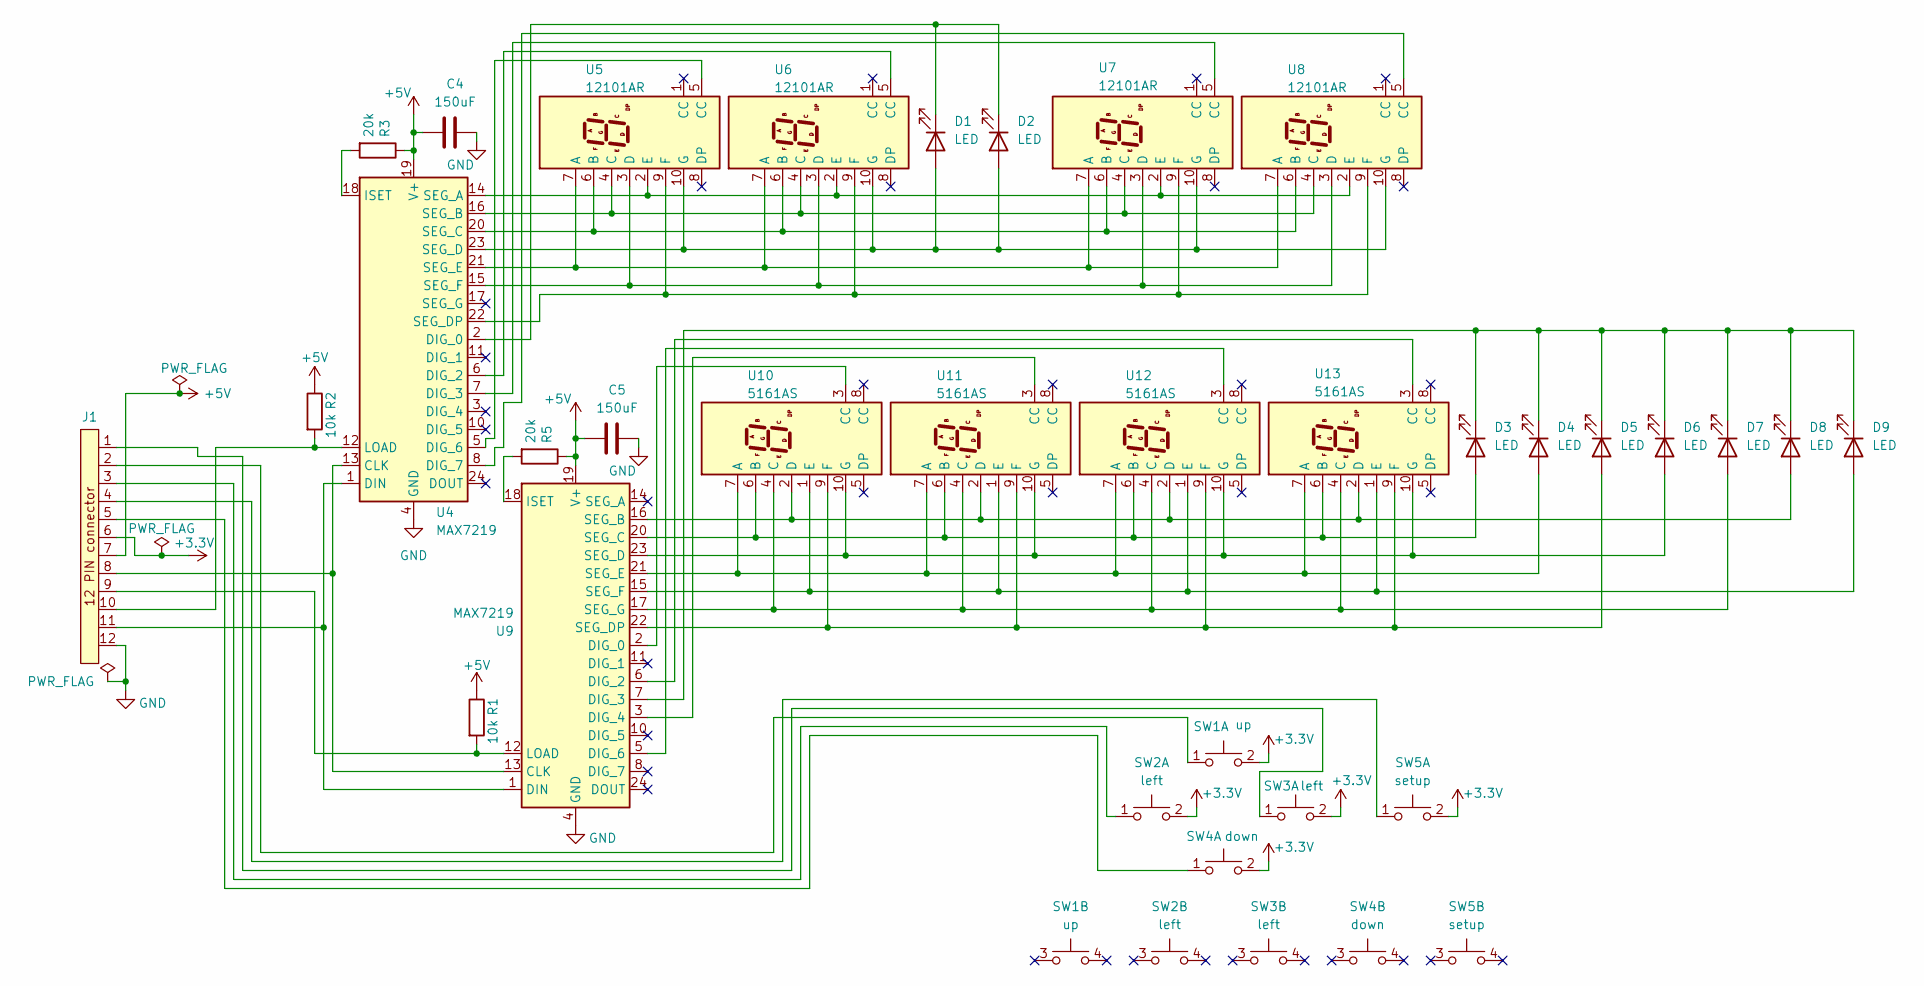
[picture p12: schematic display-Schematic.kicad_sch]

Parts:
C4, C5: 150uF; C_Rect_L7.2mm_W3.0mm_P5.00mm_FKS2_FKP2_MKS2_MKP2
D1, D2, D3, D4, D5, D6, D7, D8, D9: LED; LED_D5.0mm
J1: IDC-Header_2x06_P2.54mm_Vertical
R1, R2: 10k; R_Axial_DIN0207_L6.3mm_D2.5mm_P10.16mm_Horizontal
R3, R5: 20k; R_Axial_DIN0207_L6.3mm_D2.5mm_P10.16mm_Horizontal
SW1: up; SW_PUSH_6mm
SW2, SW3: left; SW_PUSH_6mm
SW4: down; SW_PUSH_6mm
SW5: setup; SW_PUSH_6mm
U4, U9: MAX7219; DIP-24_W7.62mm
U5, U6, U7, U8: 12101AR
U10, U11, U12, U13: 5161AS

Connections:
+3.3V: J1.6, SW1.2 (D), SW2.2 (D), SW3.2 (D), SW4.2 (D), SW5.2 (D)
+5V: C4.1, C5.1, J1.7, R1.1, R2.1, R3.1, R5.1, U4.19 (V+), U9.19 (V+)
GND: C4.2, C5.2, J1.12, U4.4 (GND), U4.9 (GND), U9.4 (GND), U9.9 (GND)
unnamed: D1.2 (A), D2.2 (A), U4.23 (SEG_D), U5.10 (G), U6.10 (G), U7.10 (G), U8.10 (G)
unnamed: D1.1 (K), D2.1 (K), U4.2 (DIG_0)
unnamed: D3.2 (A), U9.20 (SEG_C), U10.6 (B), U11.6 (B), U12.6 (B), U13.6 (B)
unnamed: D3.1 (K), D4.1 (K), D5.1 (K), D6.1 (K), D7.1 (K), D8.1 (K), D9.1 (K), U9.7 (DIG_3)
unnamed: D4.2 (A), U9.21 (SEG_E), U10.7 (A), U11.7 (A), U12.7 (A), U13.7 (A)
unnamed: D5.2 (A), U9.22 (SEG_DP), U10.9 (F), U11.9 (F), U12.9 (F), U13.9 (F)
unnamed: D6.2 (A), U9.23 (SEG_D), U10.10 (G), U11.10 (G), U12.10 (G), U13.10 (G)
unnamed: D7.2 (A), U9.17 (SEG_G), U10.4 (C), U11.4 (C), U12.4 (C), U13.4 (C)
unnamed: D8.2 (A), U9.16 (SEG_B), U10.2 (D), U11.2 (D), U12.2 (D), U13.2 (D)
unnamed: D9.2 (A), U9.15 (SEG_F), U10.1 (E), U11.1 (E), U12.1 (E), U13.1 (E)
unnamed: J1.2, SW1.1 (C)
unnamed: J1.3, SW2.1 (C)
unnamed: J1.1, SW3.1 (C)
unnamed: J1.5, SW4.1 (C)
unnamed: J1.4, SW5.1 (C)
unnamed: J1.8, U4.13 (CLK), U9.13 (CLK)
unnamed: U4.6 (DIG_2), U6.5 (CC)
unnamed: U4.7 (DIG_3), U7.5 (CC)
unnamed: U4.5 (DIG_6), U5.5 (CC)
unnamed: U4.8 (DIG_7), U8.5 (CC)
unnamed: J1.11, U4.1 (DIN), U9.1 (DIN)
unnamed: R3.2, U4.18 (ISET)
unnamed: J1.10, R2.2, U4.12 (LOAD)
unnamed: U4.14 (SEG_A), U5.2 (E), U6.2 (E), U7.2 (E), U8.2 (E)
unnamed: U4.16 (SEG_B), U5.4 (C), U6.4 (C), U7.4 (C), U8.4 (C)
unnamed: U4.20 (SEG_C), U5.6 (B), U6.6 (B), U7.6 (B), U8.6 (B)
unnamed: U4.22 (SEG_DP), U5.9 (F), U6.9 (F), U7.9 (F), U8.9 (F)
unnamed: U4.21 (SEG_E), U5.7 (A), U6.7 (A), U7.7 (A), U8.7 (A)
unnamed: U4.15 (SEG_F), U5.3 (D), U6.3 (D), U7.3 (D), U8.3 (D)
unnamed: U9.2 (DIG_0), U10.3 (CC)
unnamed: U9.6 (DIG_2), U13.3 (CC)
unnamed: U9.3 (DIG_4), U11.3 (CC)
unnamed: U9.5 (DIG_6), U12.3 (CC)
unnamed: R5.2, U9.18 (ISET)
unnamed: J1.9, R1.2, U9.12 (LOAD)

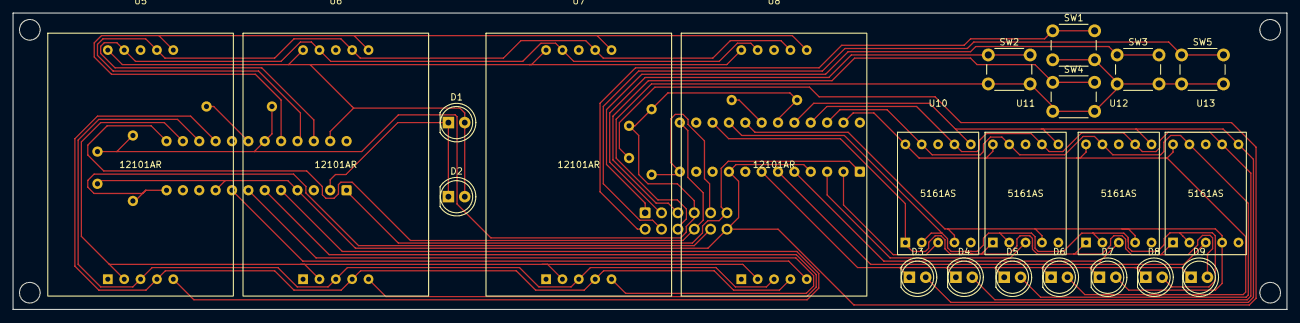
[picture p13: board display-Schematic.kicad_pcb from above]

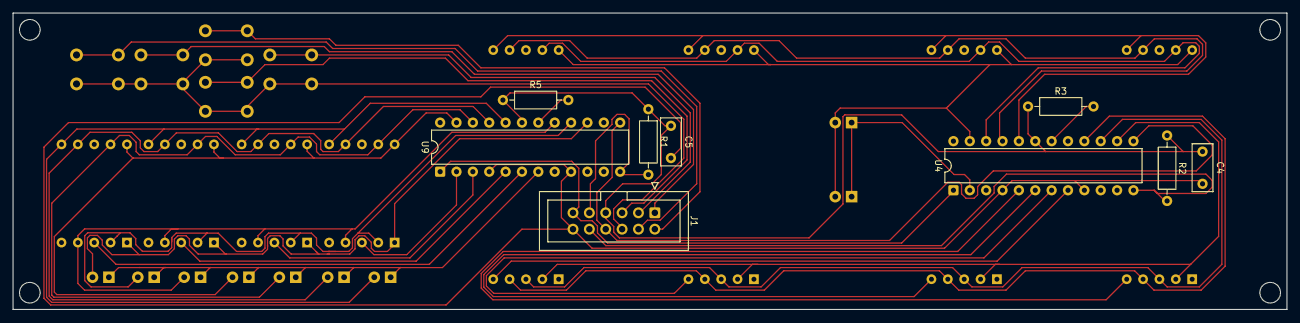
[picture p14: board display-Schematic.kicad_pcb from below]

Board: 2 copper layers, 197.7 x 46.0 mm, 31 parts (9 on the bottom side), 38 nets.

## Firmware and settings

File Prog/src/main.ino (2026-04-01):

/*
+-----------------------------------------------+
|                                               |
| Ajout du setup                                |
| Projet Reveil                                 |
| setupMode.ino                                 |
| Lidwyn Le Bars 08/08/2025                     |
+-----------------------------------------------+
*/

#include <avr/sleep.h>        // sommeil/mode eco du cpu
#include <avr/interrupt.h>    // interruptions
#include <Wire.h>             // bus I2C
#include "DS3231.h"           // DS3231
#include "AT24C32.h"          // AT24C32
#include "MAX7219.h"          // MAX7219
#include <AltSoftSerial.h>      // Necessary for DFPlayer
#include "DFPlayer.h"         // DFPlayer

#define PB6_OUT()   DDRB |= (1 << DDB6)
#define PB6_HIGH()  PORTB |= (1 << PORTB6)
#define PB6_LOW()   PORTB &= ~(1 << PORTB6)

//partie interruption
volatile bool RTCFlag = false;
volatile bool RTCLastPinState = LOW;
volatile bool refreshNextAlarmDislpay = false;

//addresse des éléments du bus I2C
const uint8_t DS3231addr = 0x68;
const uint8_t AT24C32addr = 0x57;

//variable de calcul des reveils
uint8_t timeData[6];
uint8_t AlarmNU[45];
uint8_t AlarmU[30];
uint8_t ActiveNU[45];
uint8_t ActiveU[30];
uint8_t nbAlarm = 0;
uint8_t nbActive = 0;
uint8_t nextAlarmIndex;
bool AlarmIsActive = false;

//variable de mode reveil
volatile uint8_t mode = 0; // 0: normal, 1: setup, 2: menu alarm, 3: alarm audio

//variable de setup
bool setupIsInit = false;
uint8_t newTimeData[7]; // traitement en amont des valeurs à envoyer dans le DS3231
uint8_t isSetting;
uint8_t selected = 1; // 0: heure, 1: minutes, 2: secondes, 3: jour(date), 4: mois, 5: année 
unsigned long lastBlink = 0; // variable de test pour le clignotement
bool setupIsBlinking = 0; // 0: éteint, 1: allumé
const unsigned long blinkTime = 500; // clignotement de 500ms (f = 1Hz)
unsigned long BtLastReg = 0; // Variable de dernière itération de l'utilisation du bouton (haut ou bas)
const unsigned long BtRegPeriod = 100; // Période entre chaque itération de l'utilisation du bouton
const unsigned long BtRegFirstPeriod = 500; // Période avant la première itération de l'utilisation du bouton
bool FirstRegDone = false; // Sert à savoir si la premère itération a été réalisée
bool LRHysteresis = false; // Variable permettant la mise en place d'un cycle d'hystérésis sur l'utilisation des boutons gauche et droite

//variable du menu reveil
uint8_t selectedAlarm = 1; // alarme selectionnée
bool selectedType = 0; // type d'alarme selectionnée (unique/non unique)
bool menuReveilInit = false;
bool confirmDelete = false;
bool settingAlarm = false;
bool settingAlarmInit = false;
bool alarmIsNew = false;
bool UDHysteresis = false; // Variable permettant la mise en place d'un cycle d'hystérésis sur l'utilisation des boutons haut et bas
// réutilisation de newTimeData, isSetting et selected
// réutilisation de lastBlink, setupIsBlinking et blinkTime

//timing
unsigned long lastSecond = 0;
uint8_t lastMinute = 61;
const unsigned long secondInterval = 1000;

//variable d'affichage
uint8_t displayTime[2];
bool showDoubleDot = true;
uint8_t displayNextAlarm[3];

//night mode
volatile bool nightMode = false;

//creation des éléments MAX7219 et de leur pin cs associé (SPI)
MAX7219 myMAX7219_1(12);
MAX7219 myMAX7219_2(11);
bool ddot = true; //variable d'affichage des deux points
volatile uint8_t brightness = 0x03; // Variable de luminosité des afficheurs (entre 0x00 et 0x0F)
volatile bool brightnessFlag = false;

//numeral code for MAX7219/7seg from 0 to 9
const uint8_t NumeralCode1[10] = {
  0b11110110,
  0b00110000,
  0b01011110,
  0b00111111,
  0b10111000,
  0b10101110,
  0b11101110,
  0b00110100,
  0b11111110,
  0b10111110
};

const uint8_t NumeralCode2[10] = {
  0b10110111,
  0b00010001,
  0b00111110,
  0b00111101,
  0b10011001,
  0b10101101,
  0b10101111,
  0b00010101,
  0b10111111,
  0b10111101
};

//address adaptator for MAX7219/7seg, address x != DIGx
const uint8_t MAXAddress1[5] = {
  0x08, // digit 4 = DIG7 (from right to left on the display)
  0x04, // digit 3 = DIG3
  0x03, // digit 2 = DIG2
  0x07, // digit 1 = DIG6
  0x01  // ddot = DIG0
};

const uint8_t MAXAddress2[5] = {
  0x03, // digit 4 = DIG2 (from right to left on the display)
  0x07, // digit 3 = DIG6
  0x05, // digit 2 = DIG4
  0x01, // digit 1 = DIG0
  0x04  // leds = DIG3
};

// Buttons PIN
uint8_t btPlus = 5;         // + button on D5 / PIN 11 / PCINT21
bool btPlusLastState = false; // Save the last value of the button for better fluidity in setup/alarm modes
uint8_t btMoins = 7;        // - button on D7 / PIN 13 / PCINT23
bool btMoinsLastState = false; // Save the last value of the button for better fluidity in setup/alarm modes
uint8_t btSetup = 3;        // Setup button on D3 / PIN 5 / PCINT19
uint8_t btA = 4;            // Top button on D4 / PIN 6 / PCINT20
uint8_t btGauche = 2;       // Left button on D2 / PIN 4 / PCINT18
bool btGaucheLastState = false; // Save the last value of the button for better fluidity in setup/alarm modes
uint8_t btDroite = 6;       // Right Button on D6 / PIN 12 / PCINT22
bool btDroiteLastState = false; // Save the last value of the button for better fluidity in setup/alarm modes

//Audio
const uint8_t DFPrx = 8; // to TX
const uint8_t DFPtx = 9; // to RX
// const uint8_t DFPpower = A0; // Not A0 but PB6 which doesn't have number in the standard Arduino core
AltSoftSerial DFPlayerPort; // RX = D8/PB0 TX = D9/PB1 (forced)
bool isAwake = false;
bool isReset = false;
unsigned long alarmWakeUpTimer = 0; // This timer is for the delay between the DFPlayer turning on and the first UART transmission
const unsigned long wakeUpTime = 900; // From testing, 900 ms was the smallest amount of time necessary
// réutilisation de lastBlink, setupIsBlinking et blinkTime

void setup() { //-------------------------------------------------setup
  unsigned long setupTimer = millis(); // Setup duration and for DFPlayer setup timer
  Serial.begin(9600); // Debug serial port at 9600 bauds

  //Audio
  pinMode(DFPrx, OUTPUT);
  pinMode(DFPtx, OUTPUT);
  PB6_LOW();
  PB6_OUT(); // Same as digitalWrite(DFPpower, LOW);
  // Turning the DFPlayer on for setup (low = on --> mosfet P-channel)
  // 1 sec delay necessary after this, so the rest of the setup is found at the end 
  
  for(uint8_t i = 0; i < 20; i++){ 
    Serial.println(); //serial clear
  }
  Serial.println("Hello from ATmega328P !");
  //Display init
  MAX7219::begin(13, 10, &Serial);
  myMAX7219_1.init();
  myMAX7219_2.init();


  delay(200);
  //Turning the display on while setup
  myMAX7219_1.send(MAXAddress1[0], 0xff);  // Turning on all the led for every 7-seg
  myMAX7219_1.send(MAXAddress1[1], 0xff);
  myMAX7219_1.send(MAXAddress1[2], 0xff);
  myMAX7219_1.send(MAXAddress1[3], 0xff);
  myMAX7219_1.send(MAXAddress1[4], 0xff);

  myMAX7219_2.send(MAXAddress2[0], 0xff);
  myMAX7219_2.send(MAXAddress2[1], 0xff);
  myMAX7219_2.send(MAXAddress2[2], 0xff);
  myMAX7219_2.send(MAXAddress2[3], 0xff);
  myMAX7219_2.send(MAXAddress2[4], 0xff);

  //I2C init
  Wire.begin(); // wire.h setup for I2C bus
  DS3231::begin(DS3231addr, true, &Serial);
  AT24C32::begin(AT24C32addr, true, &Serial);

  //Interruption clock (1hz so two interruption per second -> passage 0-1 et 1-0)
  pinMode(A3, INPUT);         // DS3131 clock input on A3 (PC3)
  PCICR |= (1 << PCIE1);      // Activing interruptions on PCINT[14:8] --> PC0 to PC5 / A0 to A5
  PCMSK1 |= (1 << PCINT11);   // Activing interruption specifically on PCINT11 --> PC3 / A3
  
  //Interruption boutons
  PCICR |= (1 << PCIE2);      // Activing interruptions on PCINT[16:23] --> PD0 to PD7 / D0 to D7

  pinMode(btPlus, INPUT);     // pinMode button
  PCMSK2 |= (1 << PCINT21);   // Activing interruption
  pinMode(btMoins, INPUT);
  PCMSK2 |= (1 << PCINT23);
  pinMode(btSetup, INPUT);
  PCMSK2 |= (1 << PCINT19);
  pinMode(btA, INPUT);
  PCMSK2 |= (1 << PCINT20);
  pinMode(btGauche, INPUT);   // No interruption on left button -> can upgrade the device through this button
  pinMode(btDroite, INPUT);
  PCMSK2 |= (1 << PCINT22);
  
  sei();  // Activing interruptions globaly

  set_sleep_mode(SLEEP_MODE_PWR_DOWN);
  if(false){ // I2C bus debug
    //write eeprom
    /*
    Wire.beginTransmission(AT24C32addr);
    Wire.write(0x00); //adresse haute
    Wire.write(54); //adresse basse
    Wire.write(0b00010101);
    Wire.write(0b00010110);
    Wire.endTransmission();
    delay(50);
    */
    /*
    uint8_t k = 0;
    Wire.beginTransmission(AT24C32addr);
    Wire.write(0x00); //adresse haute
    Wire.write(0x00); //adresse basse
    //registre
    Wire.write(0b00000011); k++; // 1 alarme NU active
    Wire.write(0x00); k++; //r
    Wire.write(0x00); k++; //r
    Wire.write(0x00); k++; //r
    Wire.write(0b00000011); k++; // 1 alarme U active
    Wire.write(0x00); k++; //r
    Wire.write(0x00); k++; //r
    Wire.write(0x00); k++; //r
    //zone NU
    Wire.write(0b11000101); k++; // 45min + actif
    Wire.write(0b00001000); k++; // 8h
    Wire.write(0b00011111); k++; // lundi - vendredi
    Wire.endTransmission();
    delay(200);
    //ecriture de 0;
    while(k < 54){
      Wire.beginTransmission(AT24C32addr);
      Wire.write(0x00); //adresse haute
      Wire.write(k); //adresse basse
      Wire.write(0x00); //write 0s
      Wire.endTransmission();
      delay(50);
      k++;
    }

    Wire.beginTransmission(AT24C32addr);
    Wire.write(0x00); //adresse haute
    Wire.write(54); //adresse basse 54
    //zone U
    Wire.write(0b10010101); k++; // 15min + actif
    Wire.write(0b00010110); k++; // 16h
    Wire.endTransmission();
    delay(50);
    //ecriture de 0;
    while(k < 84){
      Wire.beginTransmission(AT24C32addr);
      Wire.write(0x00); //adresse haute
      Wire.write(k); //adresse basse
      Wire.write(0x00); //write 0s
      Wire.endTransmission();
      delay(50);
      k++;
    }
    */

    
    //read all eeprom for debug
    /*
    Serial.println("--- Read AT24C32 ---");
    uint8_t j = 0;
    while(j < 84){
      Wire.beginTransmission(AT24C32addr);
      Wire.write(0x00); //adresse haute
      Wire.write(j); //adresse basse
      Wire.endTransmission();
      Wire.requestFrom(AT24C32addr, (uint8_t)1);
      Serial.print(j);
      Serial.print(" : ");
      Serial.println(Wire.read(), BIN);
      delay(50);
      j++;
    }
    */
    

    /*
    //write DS3231
    Wire.beginTransmission(DS3231addr);
    Wire.write(0x0E);
    Wire.write(0);
    Wire.endTransmission();
    

    
    //read DS3231
    Serial.println("--- read DS3231 ---");
    uint8_t k = 0;
    Wire.beginTransmission(DS3231addr);
    Wire.write(0x00);
    Wire.endTransmission();
    Wire.requestFrom((int)DS3231addr, 16);
    while (Wire.available() && k < 16) {
      Serial.println(Wire.read(),BIN);
    }
    */
  }
  
  //Time read setup
  DS3231::readFullDate(timeData);
  displayTime[0] = timeData[0];
  displayTime[1] = timeData[1];

  //Stored Alarm read setup
  nbAlarm = AT24C32::readAll(AlarmNU, AlarmU);
  nbActive = AT24C32::readActive(ActiveNU, ActiveU);

  //Next alarm setup
  nextAlarmIndex = findNextActiveAlarm(timeData, ActiveNU, (nbActive & 0xf0)>>4, ActiveU, nbActive & 0x0f);
  displayAlarm(nextAlarmIndex, ActiveNU, ActiveU, displayNextAlarm);
  
  //Audio rest of setup  
  while((millis() - setupTimer) < secondInterval){ //we check if we waited 1 sec after turning on the DFPlayer dure min 1 seconde
    delay(50);
  }
  DFPlayerPort.begin(9600);
  DFPLAYER::begin(&DFPlayerPort, DFPrx, DFPtx, &Serial);
  delay(50);
  DFPLAYER::toSleep();
  //Turning of the display
  myMAX7219_1.send(MAXAddress1[0], 0);
  myMAX7219_1.send(MAXAddress1[1], 0);
  myMAX7219_1.send(MAXAddress1[2], 0);
  myMAX7219_1.send(MAXAddress1[3], 0);
  myMAX7219_1.send(MAXAddress1[4], 0);

  myMAX7219_2.send(MAXAddress2[0], 0);
  myMAX7219_2.send(MAXAddress2[1], 0);
  myMAX7219_2.send(MAXAddress2[2], 0);
  myMAX7219_2.send(MAXAddress2[3], 0);
  myMAX7219_2.send(MAXAddress2[4], 0);
  delay(500); // Black display for .5s to signal en of setup

  //First display
  myMAX7219_1.send(MAXAddress1[3], NumeralCode1[(displayTime[1] & 0b00110000)>>4]);
  myMAX7219_1.send(MAXAddress1[2], NumeralCode1[displayTime[1] & 0b00001111]);
  myMAX7219_1.send(MAXAddress1[1], NumeralCode1[(displayTime[0] & 0b01110000)>>4]);
  myMAX7219_1.send(MAXAddress1[0], NumeralCode1[displayTime[0] & 0b00001111]);

  myMAX7219_2.send(MAXAddress2[3], NumeralCode2[(displayNextAlarm[1] & 0b00110000)>>4]);
  myMAX7219_2.send(MAXAddress2[2], NumeralCode2[displayNextAlarm[1] & 0b00001111]);
  myMAX7219_2.send(MAXAddress2[1], NumeralCode2[(displayNextAlarm[0] & 0b01110000)>>4]);
  myMAX7219_2.send(MAXAddress2[0], NumeralCode2[displayNextAlarm[0] & 0b00001111]);
  myMAX7219_2.send(MAXAddress2[4], dayLedsCompute(displayNextAlarm[2]));
  Serial.println("setup end");
  /*Serial.println("fin setup/debut nonboucle debug");
  Serial.print("setup realise en : ");
  Serial.println((millis() - setupTimer)/1000);*/
} //-------------------------------------------------------------end setup

void loop() { //-------------------------------------------------loop
  if(mode == 0){ //----------------------------------------------normal
    if(brightnessFlag){
      myMAX7219_1.Brightness(brightness);
      myMAX7219_2.Brightness(brightness);
      brightnessFlag = false;
    }
    if(RTCFlag){
      //double loopTimer = millis(); // calcul du temps
      RTCFlag = false;
      DS3231::readDisplayTime(displayTime); // getting new time to display and later detect alarm even in night mode
      if(!nightMode){
        //display time        
        myMAX7219_1.send(MAXAddress1[3], NumeralCode1[(displayTime[1] & 0b00110000)>>4]);
        myMAX7219_1.send(MAXAddress1[2], NumeralCode1[displayTime[1] & 0b00001111]);
        myMAX7219_1.send(MAXAddress1[1], NumeralCode1[(displayTime[0] & 0b01110000)>>4]);
        myMAX7219_1.send(MAXAddress1[0], NumeralCode1[displayTime[0] & 0b00001111]);
        myMAX7219_1.send(MAXAddress1[4], ddot<<3);
        ddot = !ddot;

        if(refreshNextAlarmDislpay){
          if(nbActive != 0){
            myMAX7219_2.send(MAXAddress2[3], NumeralCode2[(displayNextAlarm[1] & 0b00110000)>>4]);
            myMAX7219_2.send(MAXAddress2[2], NumeralCode2[displayNextAlarm[1] & 0b00001111]);
            myMAX7219_2.send(MAXAddress2[1], NumeralCode2[(displayNextAlarm[0] & 0b01110000)>>4]);
            myMAX7219_2.send(MAXAddress2[0], NumeralCode2[displayNextAlarm[0] & 0b00001111]);
            myMAX7219_2.send(MAXAddress2[4], dayLedsCompute(displayNextAlarm[2]));
          }
          else {
            myMAX7219_2.send(MAXAddress2[3], 0);
            myMAX7219_2.send(MAXAddress2[2], 0);
            myMAX7219_2.send(MAXAddress2[1], 0);
            myMAX7219_2.send(MAXAddress2[0], 0);
            myMAX7219_2.send(MAXAddress2[4], 0);
          }
          refreshNextAlarmDislpay = false;
        }
      }
      else{
        myMAX7219_1.send(MAXAddress1[0], 0);
        myMAX7219_1.send(MAXAddress1[1], 0);
        myMAX7219_1.send(MAXAddress1[2], 0);
        myMAX7219_1.send(MAXAddress1[3], 0);
        myMAX7219_1.send(MAXAddress1[4], 0);

        myMAX7219_2.send(MAXAddress2[0], 0);
        myMAX7219_2.send(MAXAddress2[1], 0);
        myMAX7219_2.send(MAXAddress2[2], 0);
        myMAX7219_2.send(MAXAddress2[3], 0);
        myMAX7219_2.send(MAXAddress2[4], 0);
      }
      if (lastMinute != computeValue(displayTime[0])){ // If new min we check if there is a new alarm
        lastMinute = computeValue(displayTime[0]); // Reset lastMinute value
        if(nbActive != 0){ // We check only if there are some alarms active
          DS3231::readFullDate(timeData); // Refresh timeData (not the same as displayTime)
          AlarmIsActive = checkAlarm(timeData, ActiveNU, (nbActive & 0xf0)>>4, ActiveU, nbActive & 0x0f); // Checking if an alarm is active
          if(AlarmIsActive){
            Serial.println("!----------------------!");
            Serial.println("    Alarme detectee");
            Serial.println("!----------------------!");
            delay(100);
            mode = 3; // Going in mode 3 : ringing mode
          }
        }
        // We could use something similar to displayNextAlarm[] to simplify things, it work like that so it's not a priority
      }
      
      delay(10);
    }
    
    // Au dodo
    sleep_enable();
    sleep_cpu();
    sleep_disable();
  }
  else if(mode == 1){ //-----------------------------------------mode setup
    DS3231::setupFullDateRead(newTimeData);
    if(!setupIsInit){
      selected = 0;
      isSetting = setupSelectNew(selected, newTimeData);
      setupIsInit = true;
      PCICR = 0; // Desactiver les interruptions pendant le setup
      // Cycle hysteresis du bouton setupEnd (/!\ stop le programme, mais ça n'est pas particulièrement important);
      bool setupSwitchStillUp = digitalRead(btSetup);
      while(setupSwitchStillUp){
        delay(10);
        setupSwitchStillUp = digitalRead(btSetup);
      }
    }
    
    unsigned long now = millis(); // Dans le mode 1 et 2 on utilise plus les interruptions du DS3231 mais millis pour le clignotement et autre

    
    // Partie bouton
    const bool setupUp = digitalRead(btPlus); // Plus grande prio
    const bool setupDown = digitalRead(btMoins);
    const bool setupRight = digitalRead(btDroite);
    const bool setupLeft = digitalRead(btGauche);
    const bool setupEnd = digitalRead(btSetup); // Plus petite prio
    if(setupUp || setupDown || btPlusLastState || btMoinsLastState){ // Détection haut ou bas
      // Gestion des boutons haut et bas avec une orientation sur la fluidité d'utilisation (asynchrone avec l'itération de la boucle loop)
      // Cela permet d'appuyer sur le bouton quand on veut et pouvoir rester appuyer sans que ça bouger trop rapidement. C'est une sorte de cycle d'hystérésis
      if(btPlusLastState){
        if(setupUp){ // Cas où on garde le bouton appuyé
          const unsigned long periodTmp = FirstRegDone ? BtRegPeriod : BtRegFirstPeriod; // Choix de la période différent si c'est la première
          if(now - periodTmp >= BtLastReg){ // Itération tous les 100 ms (valeur initiale)
            BtLastReg = now;
            isSetting = modifyIsSetting(selected, true, isSetting); // Seulement dans ce cas on modifie, sinon rien
            if(!FirstRegDone){FirstRegDone = true;}
          }
        }
        else {
          btPlusLastState = false;  // Bouton relaché
          BtLastReg = 0;  // Permet des appui rapide
          FirstRegDone = false;
        }
      }
      else if(btMoinsLastState){
        if(setupDown){ // Cas où on garde le bouton appuyé
          const unsigned long periodTmp = FirstRegDone ? BtRegPeriod : BtRegFirstPeriod; // Choix de la période différent si c'est la première
          if(now - periodTmp >= BtLastReg){
            BtLastReg = now;
            isSetting = modifyIsSetting(selected, false, isSetting);
            if(!FirstRegDone){FirstRegDone = true;}
          }
        }
        else {
          btMoinsLastState = false;
          BtLastReg = 0;
          FirstRegDone = false;
        }
      }
      else { // cas premier appui
        isSetting = modifyIsSetting(selected, setupUp, isSetting);
        BtLastReg = now;
        if(setupUp){
          btPlusLastState = true;
        }
        else{
          btMoinsLastState = true;
        }
      }
    }
    else if(setupRight || setupLeft || LRHysteresis){
      if(!LRHysteresis && (setupRight || setupLeft)){ // Detection du premier appui
        if((selected + setupRight < 7) && (selected - setupLeft >= 0)){ // on test pour ne pas sortir de [0;6]
          saveSetup(selected, isSetting); // on sauvegarde la valeur qu'on vient d'ajutster
          selected = setupRight ? selected + 1 : selected - 1; // on déplace le curseur
          isSetting = setupSelectNew(selected, newTimeData);
        }
        LRHysteresis = true; // Activation du cycle d'hystérésis
      }
      else if(LRHysteresis && !setupRight && !setupLeft){
        LRHysteresis = false; // Désactivation du cycle d'hystérésis
      }
    }
    else if(setupEnd){
      saveSetup(selected, isSetting); // on sauvegarde la valeur qui est sélectionnée
      setupIsInit = false; // reset de l'initialisation du mode setup
      mode = 0; // on passe en mode normal
      RTCFlag = true; // on force un flag d'affichage normal
      bool setupSwitchStillUp = digitalRead(btSetup); // On attend d'avoir relacher le bouton setup pour sortir, pour ne pas avoir une interruptions et revenir directement dans mode 1
      refreshNextAlarmDislpay = true;
      while(setupSwitchStillUp){
        delay(10);
        setupSwitchStillUp = digitalRead(btSetup);
      }
      PCICR = (1 << PCIE1) | (1 << PCIE2); // Réactiver les interruptions à la fin
      return; // on force le redemarrage de loop()
    }
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

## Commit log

2025-09-28 added hysteresis cycle for some switches, untested
2025-09-29 Switched to full VScodium with PlatformIO and clangd. Now require Minicore to be installed in /Prog/Minicore
2025-10-01 debuged an issue with the calculation of the number of alarm existing in the storage, the reg data was shifted for no reason
    [main.ino]
2025-10-01 Major issue fixed where modifyU and modifyNU would sometimes save modification and sometimes not with a very weird behaviour. Now works properly.
    [main.ino]
2025-11-20 small change for the alarm select menu going out of bound + now setting selectedAlarm to 1 (first in the list or create a new one if empty) when switching from unique to non-unique and vice versa
2025-11-20 corrected an issue with the findNextActiveAlarm function not finding the next alarm sometimes with NU alarms, now it works fine
    [main.ino]
2025-11-28 added a KiCad project in ./Schematic/
    [Schematic.kicad_pcb, Schematic.kicad_sch]
2025-12-08 corrected a but in modifyIsSetting and modifyAlarmIsSetting, it should correct a bug with setup value goind out of bound
    [Schematic.kicad_sch]
2025-12-10 There will two PCB, one with the display and the buttons (execpt top button), and another with the hardware part. I keep the full schematic in full-schematic and I added two new project kickad projec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
    [Schematic.kicad_pcb, Schematic.kicad_sch, display-Schematic.kicad_pcb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]
2025-12-10 adjusted .gitignore, and corrected the 12 PIN IDC custom component's schematic
    [display-Schematic.kicad_sch, hardware-Schematic.kicad_sch]
2025-12-10 started working on the PCB side of the display part
    [display-Schematic.kicad_pcb, display-Schematic.kicad_sch]
2025-12-12 Making the hardware schematic ready for PCB implementation
    [hardware-Schematic.kicad_sch]
2025-12-12 USC-C to 5V DC plug added to custom lib
    [display-Schematic.kicad_sch, hardware-Schematic.kicad_sch]
2025-12-19 created pcb part for hardware size, all object, but still need layout and connections
    [hardware-Schematic.kicad_pcb, hardware-Schematic.kicad_sch]
2025-12-19 started the rooting but some thing moved and now every thing is miss placed I must start from the beginning again
    [display-Schematic.kicad_pcb, hardware-Schematic.kicad_pcb, hardware-Schematic.kicad_sch]
2025-12-23 Finished the display PCB. A lot of changes went throough to ensure only one layer was used for connections. To change : plug pin placement ; switches are now pull up ; in the code : digit codes are n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
    [display-Schematic.kicad_pcb, display-Schematic.kicad_sch]
2026-01-04 Further work on the hardware side of the pcb
    [display-Schematic.kicad_pcb, display-Schematic.kicad_sch, hardware-Schematic.kicad_pcb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]
2026-01-05 Finished the PCBs. I had to use two jumper cable. I also adjusted the position of some traces close to pins
    [display-Schematic.kicad_pcb, hardware-Schematic.kicad_pcb, hardware-Schematic.kicad_sch]
2026-01-05 Created gerber files
    [display-Schematic-B_Cu.gbr, display-Schematic-B_Mask.gbr, display-Schematic-B_Paste.gbr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]
2026-02-12 fixed the code for the actual pcb prototype
    [main.ino]
2026-02-14 corrected the issue with PB6 not being a natively supported port on arduino by righting directly in the registrers
    [main.ino]
2026-02-18 now uploading for a linux device : update platformio.ini for linux and windows in a new folder :platformioIniVersion
2026-03-24 I miss soldered a component on the pcb and when dessoldering, I scratched trace, which lead to a lot of testing. I also updated the DS3231 lib to always re-write the 0x0E registrer to activate the cl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
2026-03-24 Major bugfix, from the last update. Basically I messed up two line which lead to calling a function on a un-referenced pointer, it was still working when testing, probably because it was randomly (or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
    [main.ino]
2026-03-31 Fixed an issue with alarm detection not working when in nightmode. Now also turning night mode off after an alarm ring
    [frame.FCStd]
2026-03-31 Fixed a weird bug, I believe the DFPlayer waking up is causing a lot of weird stuff, and it was generating an error when using the I2C bus at the same time. I moved the auto desable of unique alarm a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
    [main.ino]
2026-04-01 updatade the simpleFrame. I also though I had a bug but it was a date mismatch, so I just added commentary.
    [frame.FCStd]
2026-04-01 adjusted the frame
2026-04-01 Corrected the simple frame and printing it
    [frame.FCStd]
